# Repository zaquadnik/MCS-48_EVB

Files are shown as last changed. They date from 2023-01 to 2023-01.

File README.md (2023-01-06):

# MCS-48_EVB

Simple computer system using MCS-48 family microcontroller. System contains external program memory & external data memory. The external data memory uses the 62256 (32k x 8b) SRAM memory. The microcontroller directly addresses the 256 bytes of the memory, but the system adds the possibility of bank switching using the 8243 GPIO expander. The bank switching is done in software. It can be leveraged to implement multi-tasking environment with hard task memory separation. The external data memory contains 128 banks, 256 bytes each.
The external program memory uses 8k x 8b 27C64 EPROM memory. The microcontroller max program memory size is 4kB, thus EPROM contain two 4kB banks, that can be switched using the 8243 expander. This feature is experimental, thus HW jumper is added that enables setting the EPROM's A12 line to logical '0' by connecting it to the ground.

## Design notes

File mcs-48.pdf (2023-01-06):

# Grokking the MCS-48 System

## Version 3.5.2, September 2021

# Preface

This document came into existence as the effort to collect and maintain the information about the MCS-48 microcontroller family I have access to.
The collected paperwork consists of several copied sheets from Intel databooks that age over time, slowly fading away. In addition, the resources in electronic form for this microcontroller

## family were never complete nor exhaustive. As nowadays, not everyone is lucky enough to have access to these old, big databooks, this document intends to transport all the

knowledge necessary to work with these grandfathers.
Please note that this document does not claim correctness of the contained information. Nor should you ever use it as the only reference for building critical applications.

## Five separate sources contributed to this document: - Two different versions of the "MCS-48TM Microcomputer User's Manual" The chapter "The Expanded MCS-48TM System" was found in a 1978's copy of the User's Manual while the chapter "The Single Component MCS® -48 System" was probably part of a

later revision of the User's Manual.

## - Das 8039, 8048, 8748 Brevier H. Weidner, Braunschweig The first part of this booklet is a translation of "The Single Component MCS ® -48 System" into the German language while the second part gives a very detailed description of the

family's instruction set.

## - HMOS Single-Component 8-Bit Microcomputer Intel Corporation, August 1982, Order Number 210677-001

A 9-page datasheet with an excellent instruction set table.

- Some scanned pages with details about the 8243, apparently from an old Intel databook.

## - A set of copied pages containing the 8245 product specification. The second page of the

character set is missing.

## October 2006

## Arnim Läuger

mailto: arnim.laeuger <at> gmx.net

The following are trademarks of Intel Corporation and its affiliates and may be used only to identify Intel products: BXP, CREDIT, i, ICE, ICS, im, insite, Intel, INTEL, Intelevision, Intellec, iSBC, iSBX, Library Manager, MCS, MAIN MULTIMODULE, Megachassis, Micromap, MULTIBUS, Plug-A-Bubble, PROMPT, Promware, RMX, UPI, µScope, System 2000, Micromainframe, and the combination of MCS, ICE, iSBC, iRMX or iCS and a numerical suffix.

# HMOS Single-Component 8-Bit Microcomputer

- High Performance HMOS | • Reduced Power Consumption
- Interval Timer/Event Counter | • Compatible with 8080/8085 Peripherals
- Two Single Level Interrupts | • Easily Expandable Memory and I/O
- Single 5-Volt Supply | • Up to 1.36 μs Instruction Cycle
- Over 96 Instructions; 90% Single Byte | All Instructions 1 or 2 Cycles

The Intel MCS®

-48 family are totally self-sufficient, 8-bit parallel computers fabricated on single silicon chips using Intel's advanced N-channel silicon gate HMOS process.
The family contains 27 I/O lines, an 8-bit timer/counter and on-board oscillator/clock circuits. For systems that require extra capability, the family can be expanded using MCS®
| -80/MCS® -85 peripherals.
To minimize development problems and provide maximum flexibility, a logically and functionally pin-compatible version of the ROM devices with UV-erasable user-programmable EPROM program memory is available with minor differences.
These microcomputers are designed to be efficient controllers as well as arithmetic processors. They have extensive bit handling capability as well as facilities for both binary and BCD arithmetic. Efficient use of program memory results from an instruction set consisting mostly of single byte instructions and no instructions over 2 bytes in length.
Device | Internal Memory | RAM Standby
8050AH | 4K x 8 ROM | 256 x 8 RAM | yes
8049H | 2K x 8 ROM | 128 x 8 RAM | yes
8048H | 1K x 8 ROM | 64 x 8 RAM | yes
8040AHL | none | 256 x 8 RAM | yes
8039HL | none | 128 x 8 RAM | yes
8035HL | none | 64 x 8 RAM | yes
8749H | 2K x 8 EPROM | 128 x 8 RAM | yes
8748H | 1K x 8 EPROM | 64 x 8 RAM | yes

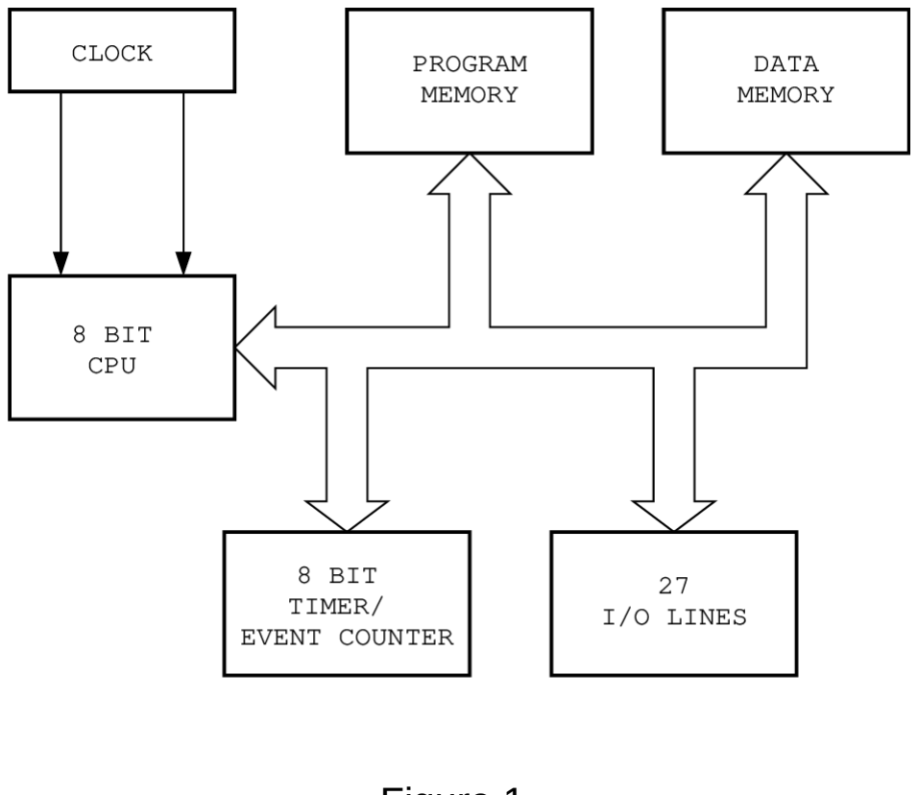
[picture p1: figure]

Figure 1.
Block Diagram

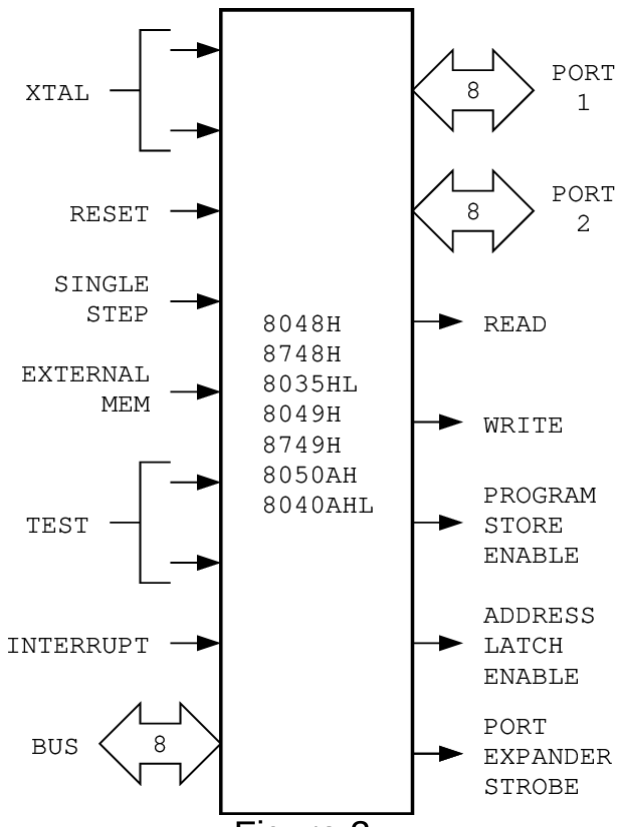
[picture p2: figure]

Figure 2.
Logic Symbol

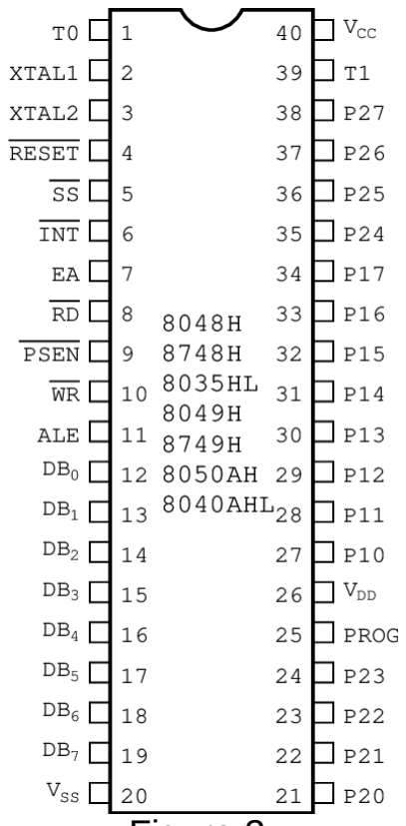
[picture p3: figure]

Figure 3.
Pin Configuration

# THE SINGLE COMPONENT MCS® -48 SYSTEM

## 1.0 INTRODUCTION

Sections 2 through 5 describe in detail the functional characteristics of the 8748H and 8749H EPROM,
8048AH/8049AH/8050AH | ROM | and | 8035AHL/
8039AHL/8040AHL CPU single component microcomputers. Unless otherwise noted, details within these sections apply to all versions. This chapter is limited to those functions useful in single-chip implementations of the MCS®

-48. The Chapter on the Expanded MCS®

| | | -48
System discusses functions which allow expansion of program memory, data memory, and input output capability.

## 2.0 ARCHITECTURE

The following sections break the MCS-48 Family into functional blocks and describe each in detail. The following description will use the 8048AH as the representative product for the family. See 4.

## 2.1 Arithmetic Section

The arithmetic section of the processor contains the basic data manipulation functions of the 8048AH and can be divided into the following blocks:
- Arithmetic Logic Unit (ALU)
- Accumulator
- Carry Flag
- Instruction Decoder

In a typical operation data stored in the accumulator is combined in the ALU with data from another source on the internal bus (such as a register or I/O port) and the result is stored in the accumulator or another register.

The following is more detailed description of the function of each block.

## INSTRUCTION DECODER

The operation code (op code) portion of each program instruction is stored in the Instruction Decoder and is converted to outputs which control the function of each of the blocks of the Arithmetic Section. These lines control the source of data and the destination register as well as the function performed in the ALU.

## ARITHMETIC LOGIC UNIT

The ALU accepts 8-bit data words from one or two sources and generates an 8-bit result under control of the Instruction Decoder. The ALU can perform the following functions:

- Add With or Without Carry
- AND, OR, Exclusive OR
- Increment/Decrement
- Bit Complement
- Rotate Left, Right
- Swap Nibbles
- BCD Decimal Adjust

If the operation performed by the ALU results in a value represented by more than 8 bits (overflow of most significant bit), the Carry Flag is set in the Program Status Word.

## ACCUMULATOR

The accumulator is the single most important data register in the processor, being one of the sources of input to the ALU and often the destination of the result of operations performed by the ALU. Data to and from I/O ports and memory also normally passes through the accumulator.

## 2.2 Program Memory

Resident program memory consists of 1024, 2048 or 4096 words eight bit wide which are addressed by the program counter. In the 8748H and the 8749H this memory is user programmable and erasable EPROM; in the 8048AH/ 8049AH/8050AH the memory is ROM which is mask programmable at the factory. The 8035AHL/8039AHL/ 8040AHL has no internal program memory and is used with external memory devices. Program code is completely interchangeable among the various versions. To access the upper 2K of program memory in the 8050AH and other MCS-48 devices, a select memory bank and a JUMP or CALL instruction must be executed to cross the 2K boundary.

There are three locations in Program Memory of special importance as shown in 5.

LOCATION 0
Activating the Reset line of the processor causes the first instruction to be fetched from location 0.

LOCATION 3
Activating the Interrupt input line of the processor (if interrupt is enabled) causes a jump to subroutine at location 3.

LOCATION 7
A timer/counter interrupt resulting from timer counter overflow (if enabled) causes a jump to subroutine at location 7.

Therefore, the first instruction to be executed after initialization is stored in location 0, the first word of an external interrupt service subroutine is stored in location 3 and the first word of a timer/counter service routines is stored in location 7. Program memory can be used to

4

## SINGLE COMPONENT MCS® -48 SYSTEM

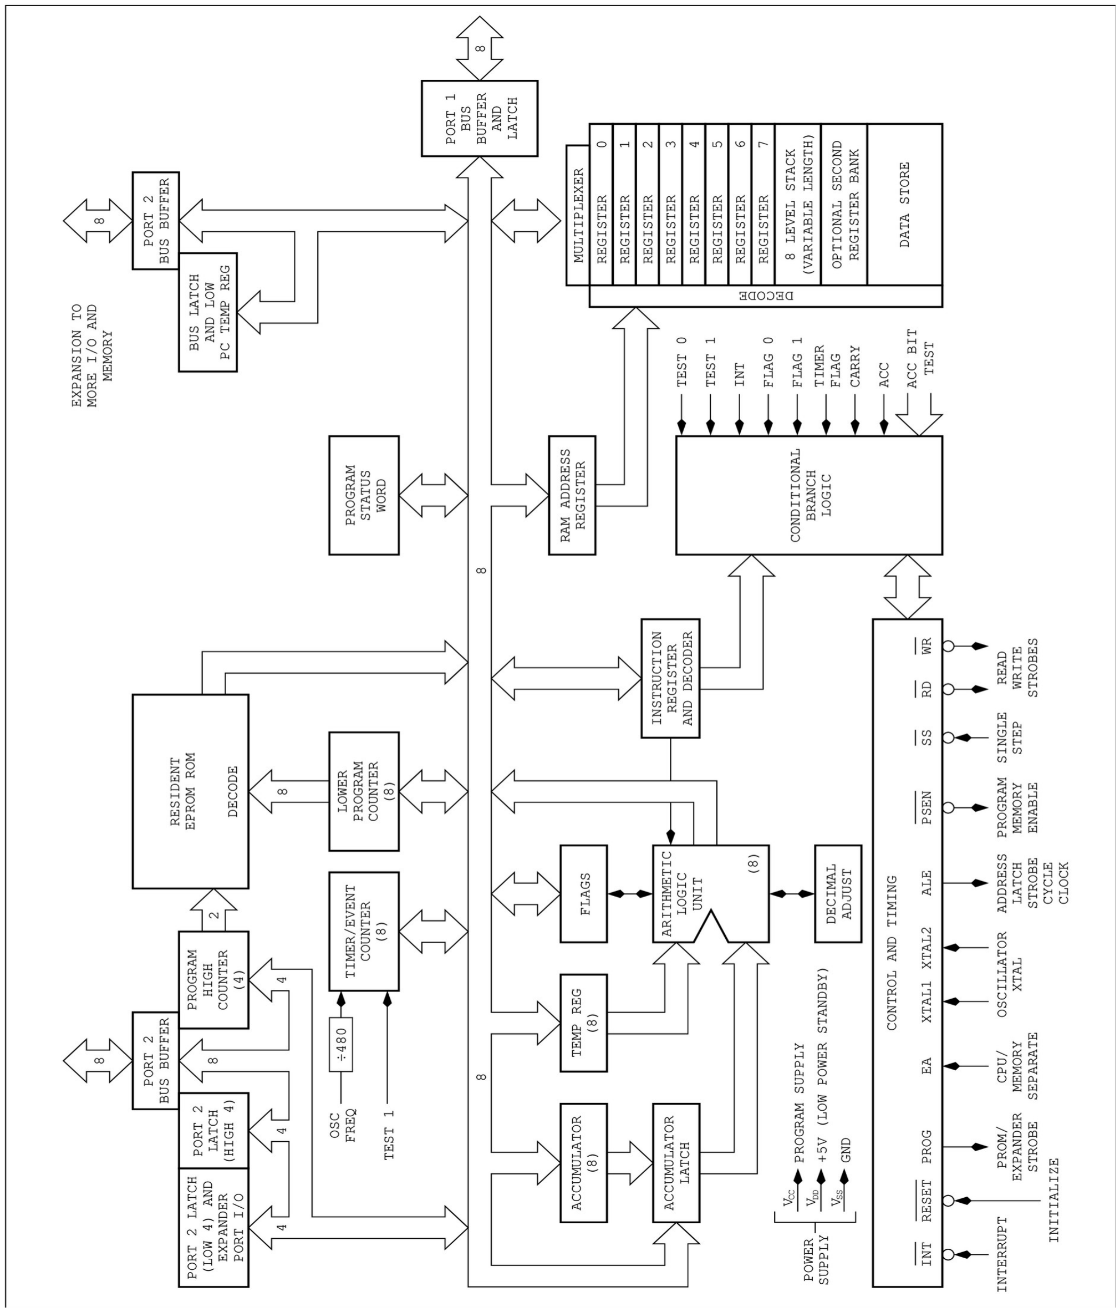
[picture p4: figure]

5

Figure 4: 8748H/8048H/8749AH/8050AH Block Diagram store constants as well as program instructions. Instructions such as MOVP and MOVP3 allow easy access to data "lookup" tables.

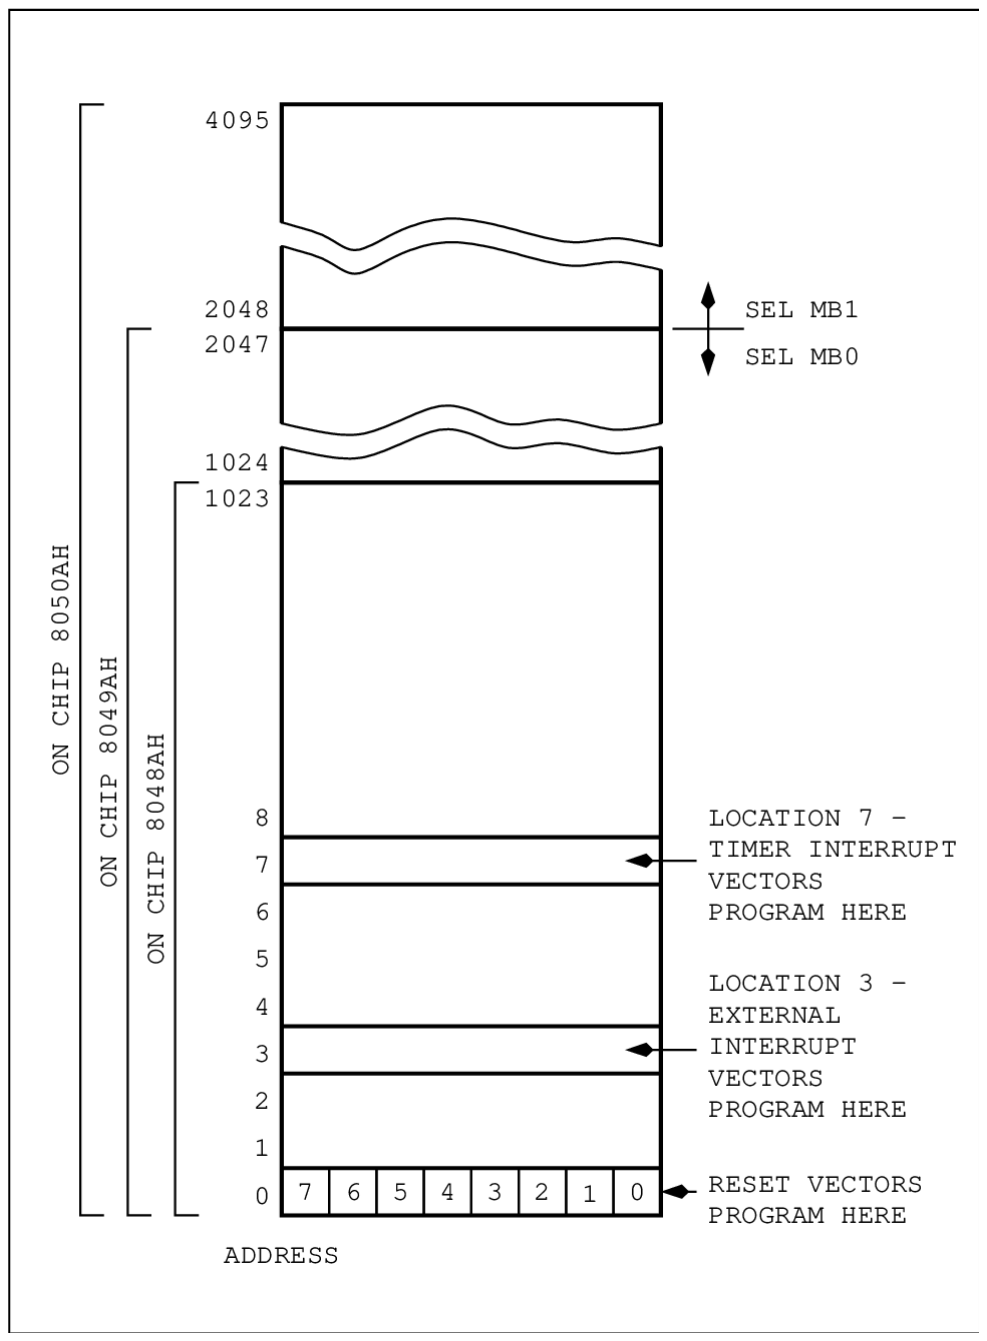
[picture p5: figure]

## 2.3 Data Memory

Resident data memory is organized as 64, 128 or 256 by 8-bits wide in the 8048AH, 8049AH and 8058AH. All locations are indirectly addressable through either of two RAM Pointer Registers which reside at address 0 and 1 of the register array. In addition, as shown in 6, the first 8 locations (0-7) of th array are designated as working registers and are directly addressable by several instructions. Since these registers are more easily addressed, they are usually used to store frequently accessed intermediate results. The DJNZ instruction makes very efficient use of the working registers as program loop counters by allowing the programmer to decrement and test the register in a single instruction.

By executing a Register Bank Switch instruction (SEL RB), RAM locations 24-31 are designated as the working registers in place of locations 0-7 and are then directly addressable. This second bank of working registers may be used as an extension of the first bank or reserved for use during interrupt service subroutines allowing the registers of Bank 0 used in the main program to be instantly "saved" by a Bank Switch. Note that if this second bank is not used, locations 24-31 are still addressable as general purpose RAM. Since the two RAM pointer Registers R0 and R1 are a part of the working register array, bank switch effectively creates two more pointer registers (R0/ and R1/) which can be used with R0 and R1 to easily access up to four separate working areas in RAM at one time. RAM locations 8-23 also serve a dual role in that they contain the program counter stack as explained in Section 2.6. These locations are addressed by the Stack Pointer during subroutine calls as well as by RAM Pointer Registers R0 and R1. If the level of subroutine nesting is less than 8, all stack registers are not required and can be used as general purpose RAM locations. Each level of subroutine nesting not used provides the user with two additional RAM locations.

6

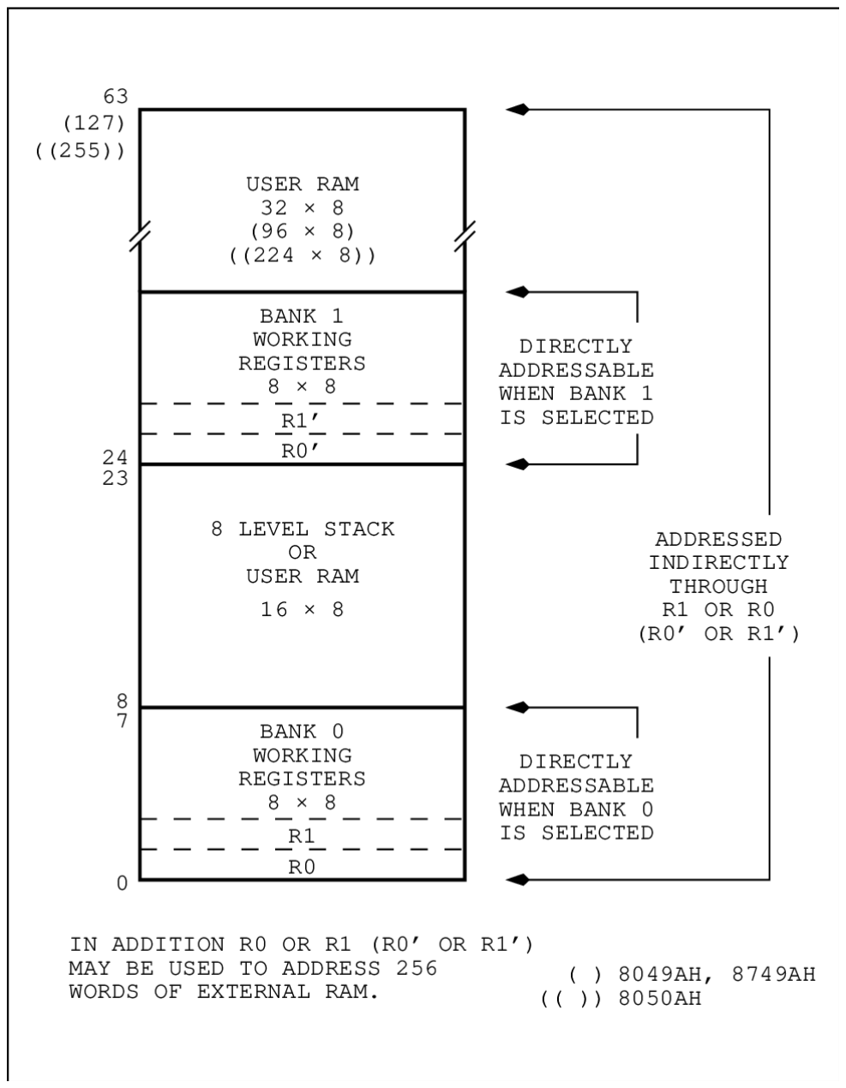
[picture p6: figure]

Figure 6. Data Memory Map

Figure 5. Program Memory Map

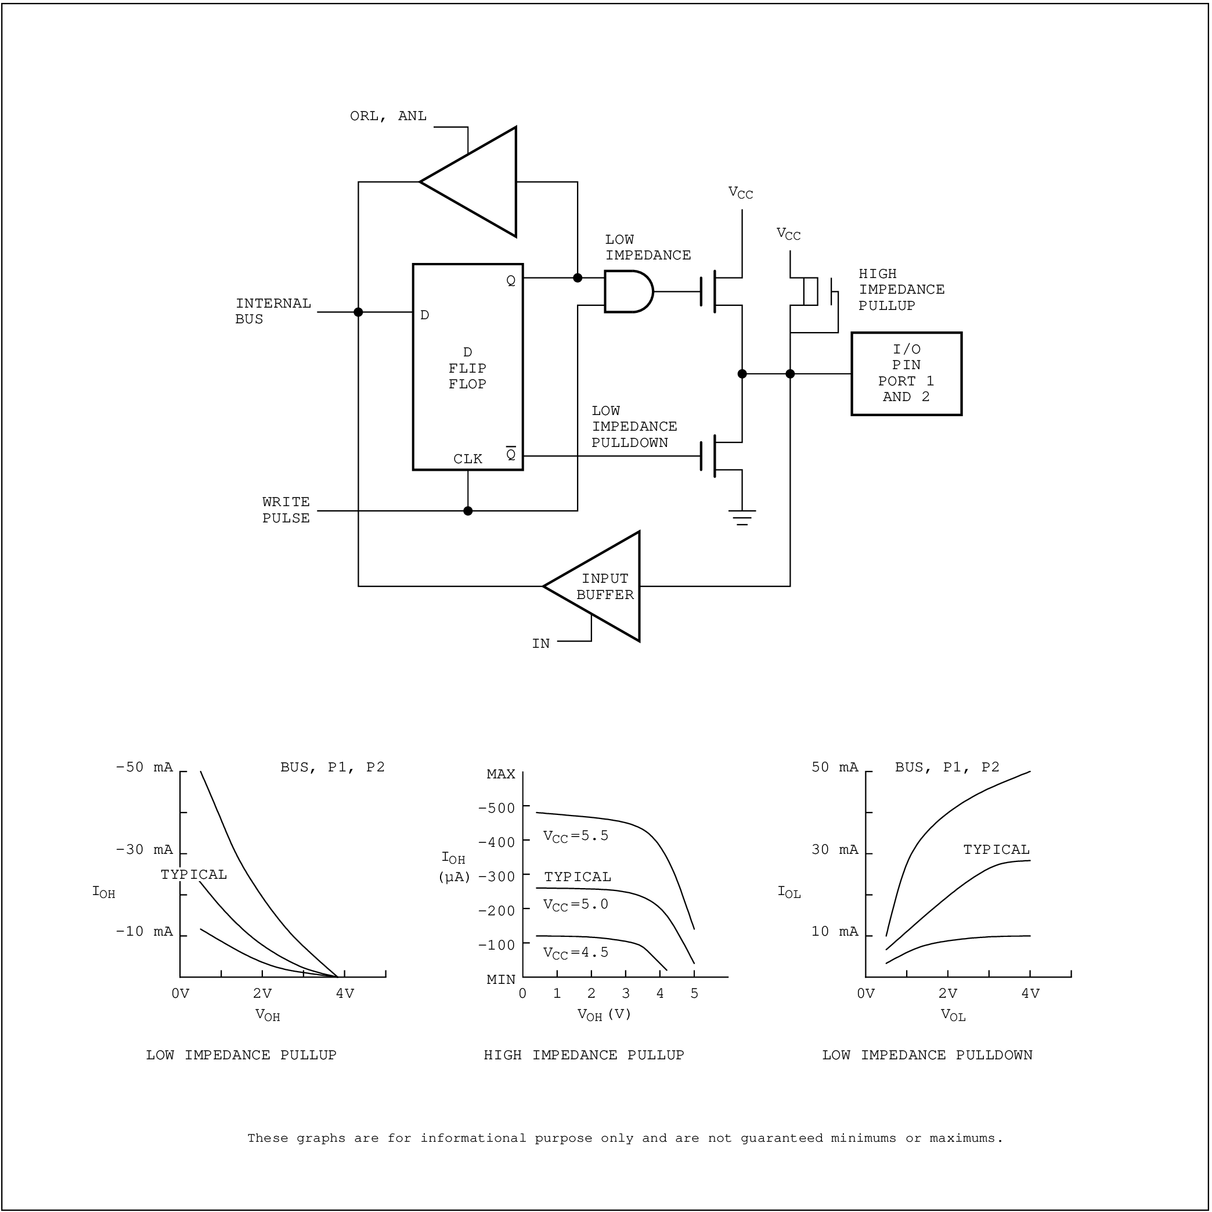
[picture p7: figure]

7

Figure 7. "Quasi-bidirectional" Port Structure

## 2.4 Input/Output

The 8048AH has 27 lines which can be used for input or output functions. These lines are grouped as 3 ports of 8 lines each which serve as either inputs, outputs or bidirectional ports and 3 "test" inputs which can alter program sequences when tested by conditional jump instructions.

## PORTS 1 AND 2

Ports 1 and 2 are each 8 bits wide and have identical characteristics. Data written to these ports is statically latched and remains unchanged until rewritten. As input ports these lines are non-latching, i. e., inputs must be present until read by an input instruction. Inputs are fully TTL compatible and outputs will drive one standard TTL load.

The lines of ports 1 and 2 are called quasi-bidirectional because of a special output circuit structure which allows each line to serve as an input and output or both even though outputs are statically latched. 7 shows the circuit configuration in detail. Each line is continuously pulled to VCC through a resistive device of relatively high impedance.

This pullup is sufficient to provide the source current for a TTL high level yet can be pulled low by a standard TTL gate thus allowing the same pin to be used for both input and output. To provide fast switching times in a "0" to "1" transition a relatively low impedance device is switched in momentarily (≈ 1/5 of a machine cycle) whenever a "1" is written to the line. When a "0" is written to the line, a low impedance device overcomes the light pullup and provides TTL current sinking capability. Since the pulldown transistor is a low impedance device a "1" must first be written to any line which is to be used as an input. Reset initializes all lines to the high impedance "1" state.

It is important to note that the ORL and the ANL are read/ write operations. When executed, the μC "reads" the port, modifies the data according to the instruction, then "writes" the data back to the port. The "writing" (essentially an OUTL instruction) enables the low impedance pull-up momentarily again even if the data was unchanged from a "1". This specifically applies to configurations that have inputs and outputs mixed together on the same port. See also section 8 in the Expanded MCS-48 System chapter.

## BUS

Bus is also an 8-bit port which is a true bidirectional port with associated input and output strobes. If the bidirectional feature is not needed, Bus can serve as either a statically latched output port or non-latching input port. Input and output lines on this port cannot be mixed however.

As a static port, data is written and latched using the OUTL instruction and inputted using the INS instruction. The INS and OUTL instructions generate pulses on the corresponding RD' and WR' output strobe lines; however, in the static port mode they are generally not used. As a bidirectional port the MOVX instructions are used to read and write the port. A write to the port generates a pulse on the WR' output line and output data is valid at the trailing edge of WR'. A read of the port generates a pulse on the RD' output line and input data must be valid at the trailing edge of RD'. When not being written or read, the BUS lines are in a high impedance state. See also sections 7 and 8 in the Expanded MCS-48 System chapter.

## 2.5 Test and INT Inputs

Three pins serve as inputs and are testable with the conditional jump instructions. These are T0, T1, and INT'. These pins allow inputs to cause program branches without the necessity to load an input port into the accumulator. The T0, T1, and INT' pins have other possible functions as well. See the pin description in Section 3.

## 2.6 Program Counter and Stack

The Program Counter is an independent counter while the Program Counter Stack is implemented using pairs of registers in the Data Memory Area. Only 10, 11 or 12 bits of the Program Counter are used to address the 1024, 2048 or 4096 words of on-board program memory of the 8048AH, 8049AH or 8050AH, while the most significant bits can be used for external Program Memory fetches. See 8. The Program Counter is initialized to zero by activating the Reset line.

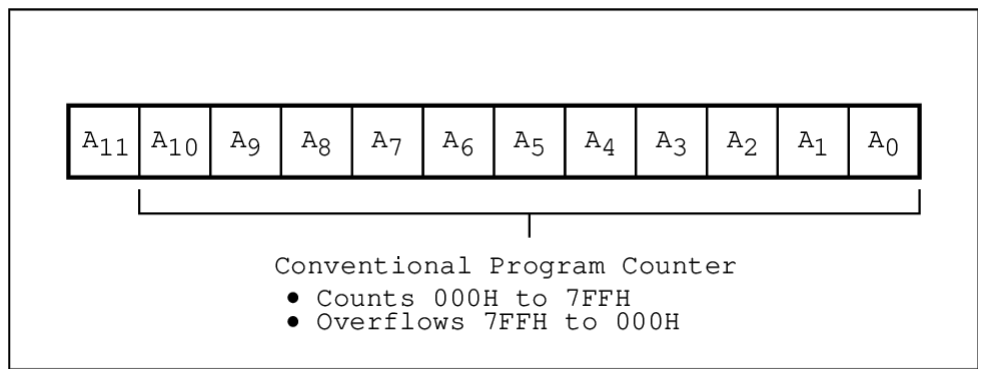
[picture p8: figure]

An interrupt or CALL to a subroutine causes the contents of the program counter to be stored in one of the 8 register pairs of the Program Counter Stack as shown in 9. The pair to be used is determined by a 3-bit Stack Pointer which is part of the Program Status Word (PSW).

8

Figure 8. Program Counter

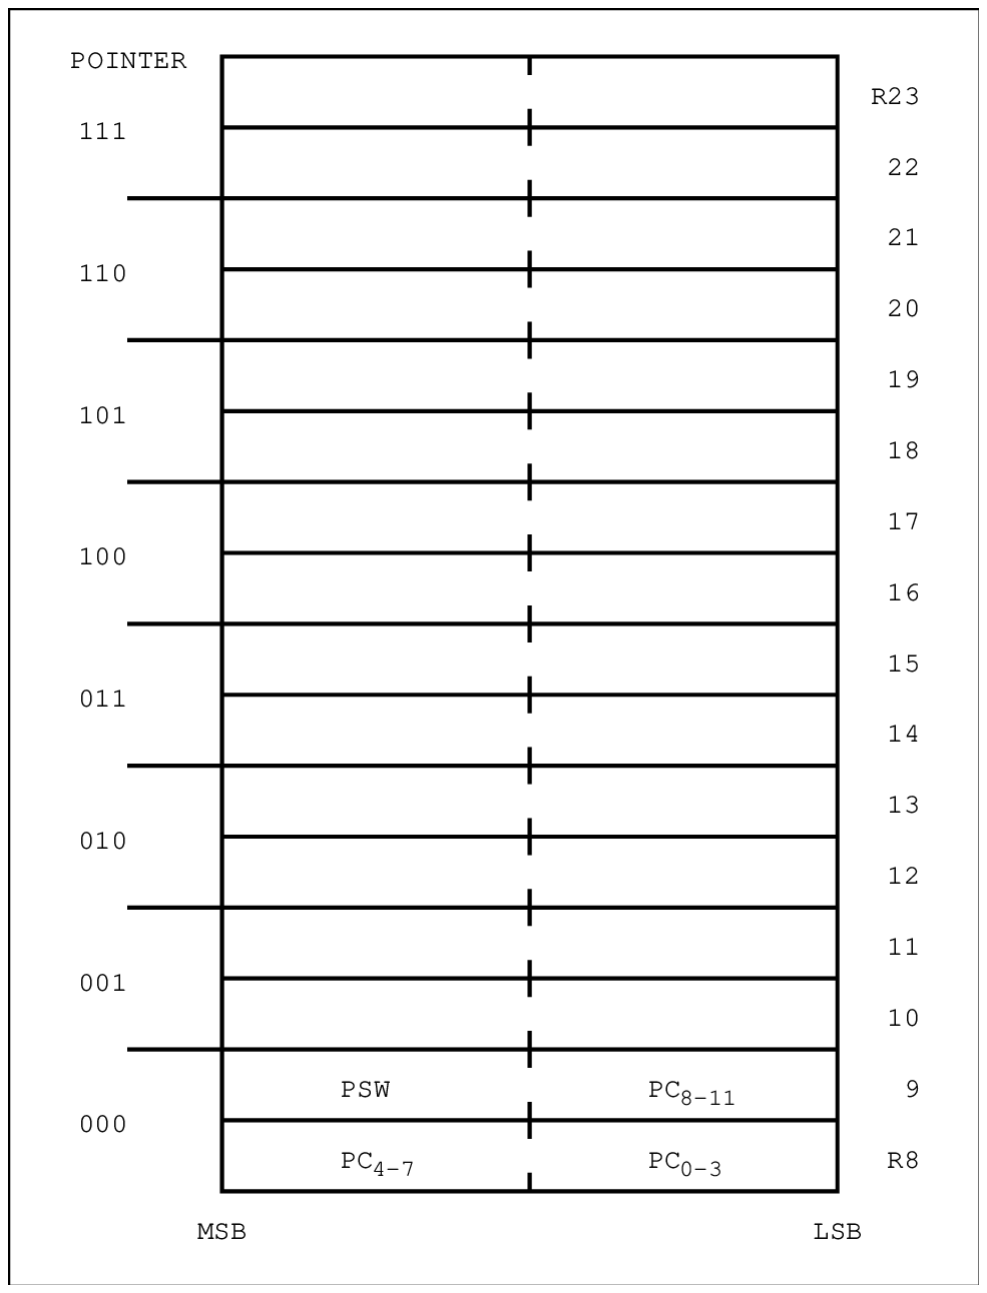
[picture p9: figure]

Data RAM locations 8-23 are available as stack registers and are used to store the Program Counter and 4 bits of PSW as shown in 9. The Stack Pointer when initialized to 000 points to RAM location 8 and 9. The first subroutine jump or interrupt results in the program counter contents being transferred to locations 8 and 9 of the RAM array. The stack pointer is then incremented by one to point to locations 10 and 11 in anticipation of another CALL. Nesting of subroutines within subroutines can continue up to 8 times without overflowing the stack. If overflow does occur, the deepest address stored (locations 8 and 9) will be overwritten and lost since the stack pointer overflows from 111 to 000. It also underflows from 000 to 111.

The end of a subroutine, which is signaled by a return instruction (RET or RETR), causes the Stack Pointer to be decremented and the contents of the resulting register pair to be transferred to the Program Counter.

## 2.7 Program Status Word

An 8-bit status word which can be loaded to and from the accumulator exists called the Program Status Word (PSW). 10 shows the information available in the word. The Program Status Word is actually a collection of flipflops throughout the machine which can be read or written as a whole. The ability to write the PSW allows for easy restoration of machine status after a power down sequence.

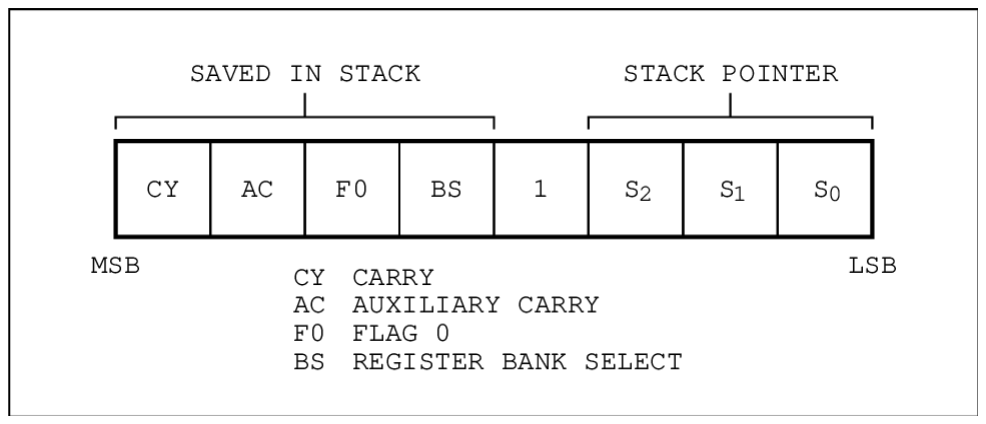
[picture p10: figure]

The upper four bits of PSW are stored in the Program Counter Stack with every call to subroutine or interrupt vector and are optionally restored upon return with the RETR instruction. The RET return instruction does not update PSW.

The PSW bit definitions are as follows:

Bits 0-2: | Stack Pointer bits (S0, S1, S2)
Bit 3: | Not used ("1" level when read)
Bit 4: | Working Register Bank Switch Bit (BS) 0 = Bank 0 1 = Bank 1
Bit 5: | Flag 0 bit (F0) user controlled flag which can be complemented or cleared and tested with the conditional jump instruction JF0.
Bit 6: | Auxiliary Carry (AC) carry bit generated by an ADD instruction and used by the decimal adjust instruction DA A.
Bit 7: | Carry (CY) carry flag which indicates that the previous operation has resulted in overflow of the accumulator.

## 2.8 Conditional Branch Logic

The conditional branch logic within the processor enables several conditions internal and external to the processor to be tested by the user program. By using the conditional jump instruction the conditions that are listed in 1 can affect a change in the sequence of the program execution.

9

Figure 10. Program Status Word (PSW)

Figure 9. Program Counter Stack

Table 1

Device Testable | Jump Condition (Jump On)
Accumulator Accumulator Bit Carry Flag User Flags (F0, F1) Timer Overflow Flag Test Inputs (T0, T1) Interrupt Input (INT) | All zeros ---0 ------0 0 | not all zeros 1 1 1 1 1 ---

## 2.9 Interrupt

An interrupt sequence is initiated by applying a low "0" level input to the INT' pin. Interrupt is level triggered and active low to allow "WIRE ORing" of several interrupt sources at the input pin. 11 shows the interrupt logic of the 8048AH. The interrupt line is sampled every instruction cycle and when detected causes a "call to subroutine" at location 3 in program memory as soon as all cycles of the current instruction are complete. On 2-cycle instructions the interrupt line is sampled on the 2nd cycle only. INT' must be held low for at least 3 machine cycles to ensure proper interrupt operations. As in any CALL to subroutine, the Program Counter and Program Status word is saved in the stack. For a description of this operation see the previous section, Program Counter and Stack. Program Memory location 3 usually contains an unconditional jump to an interrupt service subroutine elsewhere in program memory. The end of an interrupt service subroutine is signaled by the execution of a Return and Restore Status instruction RETR. The interrupt system is single level in that once an interrupt is detected all further interrupt requests are ignored until execution of an RETR reenables the interrupt input logic. This occurs at the beginning of the second cycle of the RETR instruction. This sequence holds true also for an internal interrupt generated by timer overflow. If an internal timer/counter generated interrupt and an external source will be recognized at the same time, the external source will be recognized. See the following Timer/Counter section for a description of timer interrupt. If needed, a second external interrupt can be created by enabling the timer/counter interrupt, loading FFH in the Counter (one less than terminal count) and enabling the event counter mode. A "1" to "0" transition on the T1 input will then cause an interrupt vector to location 7.

## INTERRUPT TIMING

The interrupt input may be enabled or disabled under Program Control using the EN I and DIS I instructions. Interrupts are disabled by Reset and remain so until enabled by the user's program. An interrupt request must be removed before the RETR instruction is executed upon return from the service subroutine otherwise the processor will re-enter the service routine immediately. Many peripheral devices prevent this situation by resetting their interrupt request line whenever the processor accesses (Reads or Writes) the peripheral's data buffer register. If the interrupt device does not require access by the processor, one output line of the 8048AH may be designated as an "interrupt acknowledge" which is activated by the service subroutine to reset the interrupt request. The INT' pin may also be tested using the conditional jump instruction JNI. This instruction may be used to detect the presence of a pending interrupt before interrupts are enabled. If interrupt is left disabled, INT' may be used as another test input like T0 and T1.

## 2.10 Timer/Counter

The 8048AH contains a counter to aid the user in counting external events and generating accurate time delays without placing a burden on the processor for these functions. In both modes the counter operation is the same, the only difference being the source of the input to the counter. The timer/event counter is show in 12.

## COUNTER

The 8-bit binary counter is presettable and readable with the MOV instructions which transfer the contents of the accumulator to the counter and vice versa. The counter content may be affected by Reset and should be initialized by software. The counter is stopped by a Reset or STOP TCNT instruction and remains stopped until started as a timer by a STRT T instruction or as an event counter by a STRT CNT instruction. Once started, the counter will increment to this maximum count (FF) and overflow to zero continuing its count until stopped by a STOP TCNT instruction or Reset.

The increment from maximum count to zero (overflow) results in the setting of an overflow flag flip-flop and in the generation of an interrupt request. The state of the overflow flag is testable with the conditional jump instruction JTF. The flag is reset by executing a JTF or by Reset. The interrupt request is stored in a latch and then ORed with the external interrupt input INT. The timer interrupt may be enabled or disabled independently of external interrupt by the EN TCNTI and DIS TCNTI instructions. If enabled, the counter overflow will cause a subroutine call to location 7 where the timer or counter service routine may be stored.

10

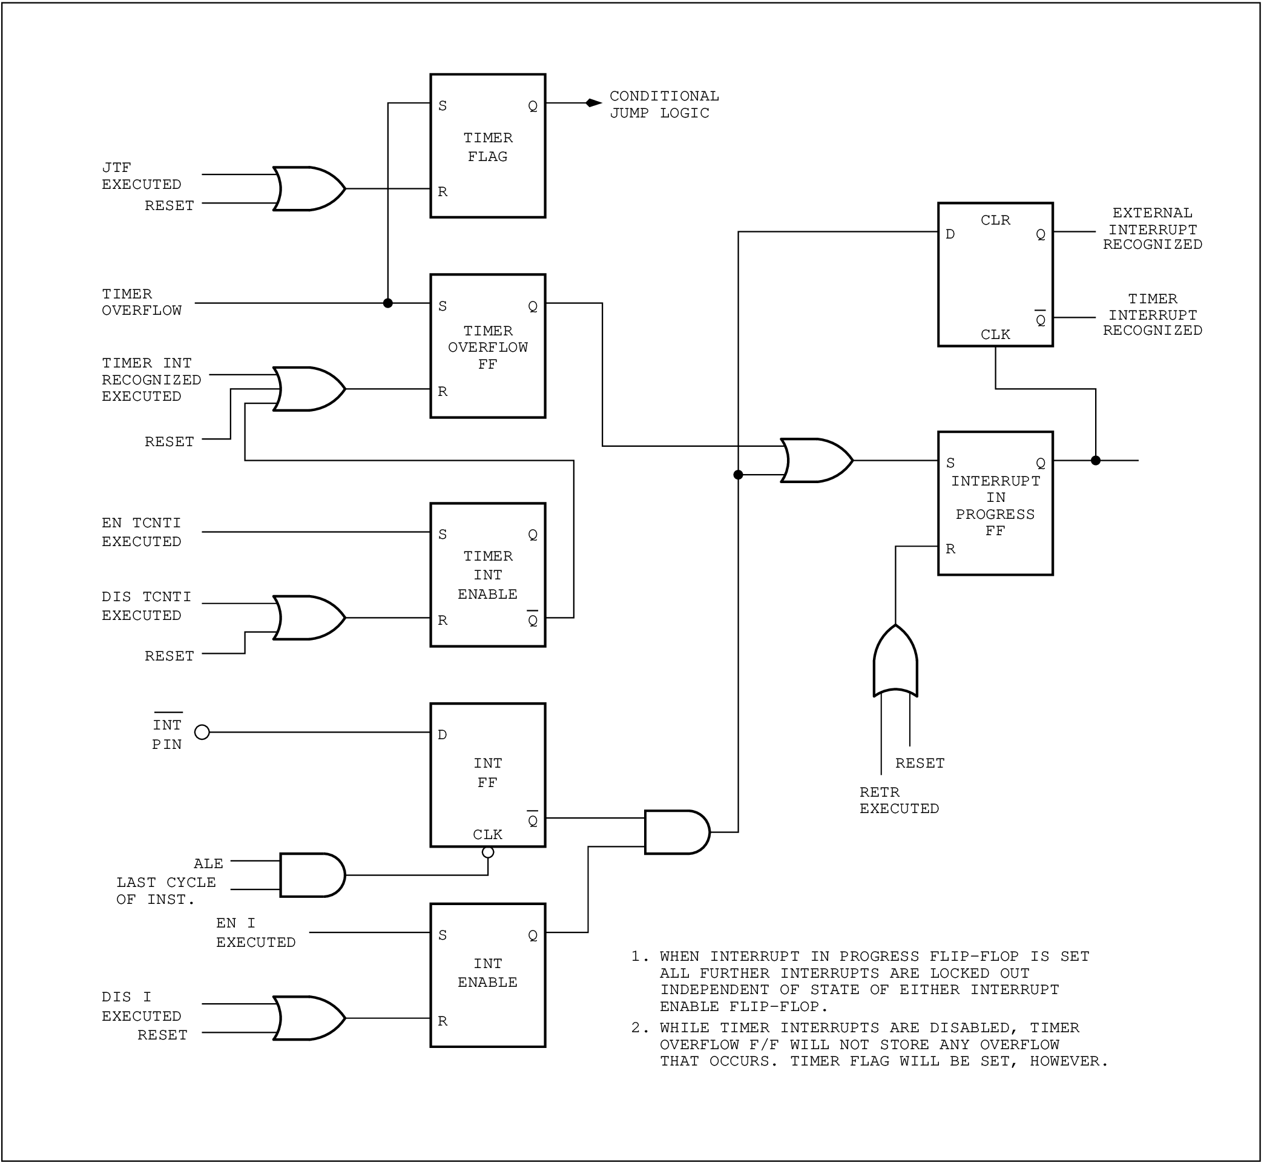
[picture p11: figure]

11

Figure 11. Interrupt Logic

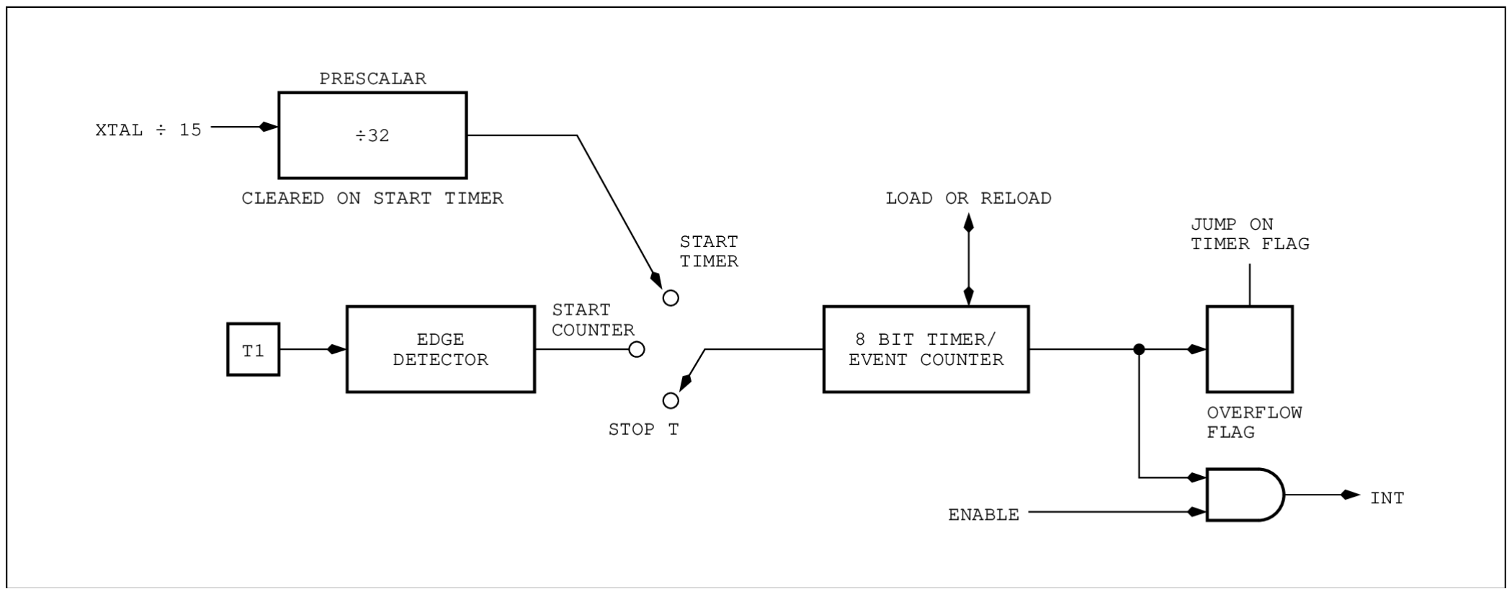
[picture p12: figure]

If timer and external interrupts occur simultaneously, the external interrupt will be recognized and the Call will be to location 3. Since the timer interrupt is latched it will remain pending until the external device is serviced and immediately be recognized upon return from the service routine. The pending timer interrupt is reset by the Call to location 7 or may be removed by executing a DIS TCNTI instruction.

## AS AN EVENT COUNTER

Execution of a START CNT instruction connects the T1 input pin to the counter input and enables the counter. The T1 input is sampled at the beginning of state 3 or in later MCS-48 devices in state time 4. Subsequent high to low transitions on T1 will cause the counter to increment. T1 must be held low for at least 1 machine cycle to ensure it won't be missed. The maximum rate at which the counter may be incremented is once per three instruction cycles (every 5.7 µsec when using an 8 MHz crystal) --- there is no minimum frequency. T1 input must remain high for at least 1/5 machine cycle after each transition.

## AS A TIMER

Execution of a START T instruction connects an internal clock to the counter input and enables the counter. The internal clock is derived by passing the basic machine cycle clock through a ÷ 32 prescaler. The prescaler is reset during the START T instruction. The resulting clock increments the counter every 32 machine cycles. Various delays from 1 to 256 counts can be obtained by presetting the counter and detecting overflow. Times longer than 256 counts may be achieved by accumulating multiple overflows in a register under software control. For time resolution less than 1 count an external clock can be applied to the T1 input and the counter operated in the event counter mode. ALE divided by 3 or more can serve as this external clock. Very small delays or "fine tuning" of larger delays can be easily accomplished by software delay loops.

Often a serial link is desirable in an MCS-48 family member. 2 lists the timer counts and cycles needed for a specific baud rate given a crystal frequency.

## 2.11 Clock and Timing Circuits

Timing generation for the 8048AH is completely self contained with the exception of a frequency reference which can be XTAL, ceramic resonator or external clock source. The Clock and Timing circuitry can be divided into the following functional blocks.

## OSCILLATOR

The on-board oscillator is a high gain parallel resonant circuit with a frequency range of 1 to 11 MHz. The X1 external pin is the input to the amplifier stage while X2 is the output. A crystal or ceramic resonator connected between X1 and X2 provides the feedback and phase shift required for oscillation. If an accurate frequency reference is not required, ceramic resonator may be used in place of the crystal.

For accurate clocking, a crystal should be used. An externally generated clock may also be applied to X1—X2 as the frequency source. See the data sheet for more information.

12

Figure 12. Timer/Event Counter

## STATE COUNTER

The output of the oscillator is divided by 3 in the State Counter to create a clock which defines the state times of the machine (CLK). CLK can be made available on the external pin T0 by executing an ENT0 CLK instruction. The output of CLK on T0 is disabled by Reset of the processor.

## CYCLE COUNTER

CLK is then divided by 5 in the Cycle Counter to provide a clock which defines a machine cycle consisting of 5 machine states as shown in 13. 14 shows the different internal operations as divided into the machine states. This clock is called Address Latch Enable (ALE) because of its function in MCS-48 systems with external memory. It is provided continuously on the ALE output pin.

## 2.12 Reset

The reset input provides a means for initialization for the processor. This Schmitt-trigger input has an internal pullup device which in combination with an external 1 µF capacitor provides an internal reset pulse of sufficient length to guarantee all circuitry is reset, as shown in 15. If the reset pulse is generated externally, the RESET pin must be held low for at least 10 milliseconds after the power supply is within tolerance. Only 5 machine cycles

(6.8 µs @ 11 MHz) are required if power is already on and the oscillator has stabilized. ALE and PSEN (if EA = 1) are active while in Reset.

Reset performs the following functions:

1) Sets program counter to zero.
2) Sets stack pointer to zero.
3) Selects register bank 0.
4) Selects memory bank 0.
5) Sets BUS to high impedance state (except when EA = 5 V).
6) Sets Ports 1 and 2 to input mode.
7) Disables interrupts (timer and external).
8) Stops timer.
9) Clears timer flag.
10) Clears F0 and F1.
11) Disables clock output from T0.

13

Table 2. Baud Rate Generation

Frequency (MHz) | TCY | T0 Prr(1/5 TCY) | Timer Prescaler (32 TCY)
4 6 8 11 | 3.75 µs 2.50 µs 1.88 µs 1.36 µs | 750 ns 500 ns 375 ns 275 ns | 120 µs 80 µs 60.2 µs 43.5 µs
Baud Rate | 4 MHz Timer Counts + Instr. Cycles | 6 MHz Timer Counts + Instr. Cycles | 8 MHz Timer Counts + Instr. Cycles | 11 MHz Timer Counts + Instr. Cycles
110 | 75 + 24 Cycles .01% Error | 113 + 20 Cycles .01% Error | 151 + 3 Cycles .01% Error | 208 + 28 Cycles .01% Error
300 | 27 + 24 Cycles .1% Error | 41 + 21 Cycles .03% Error | 55 + 13 Cycles .01% Error | 76 + 18 Cycles .04% Error
1200 | 6 + 30 Cycles .1% Error | 10 + 13 Cycles .1% Error | 12 + 27 Cycles .06% Error | 19 + 4 Cycles .12% Error
1800 | 4 + 20 Cycles .1% Error | 6 + 30 Cycles .1% Error | 9 + 7 Cycles .17% Error | 12 + 24 Cycles .12% Error
2400 | 3 + 15 Cycles .1% Error | 5 + 6 Cycles .4% Error | 6 + 24 Cycles .29% Error | 9 + 18 Cycles .12% Error
4800 | 1 + 23 Cycles 1.0% Error | 2 + 19 Cycles .4% Error | 3 + 14 Cycles .74% Error | 4 + 25 Cycles .12% Error

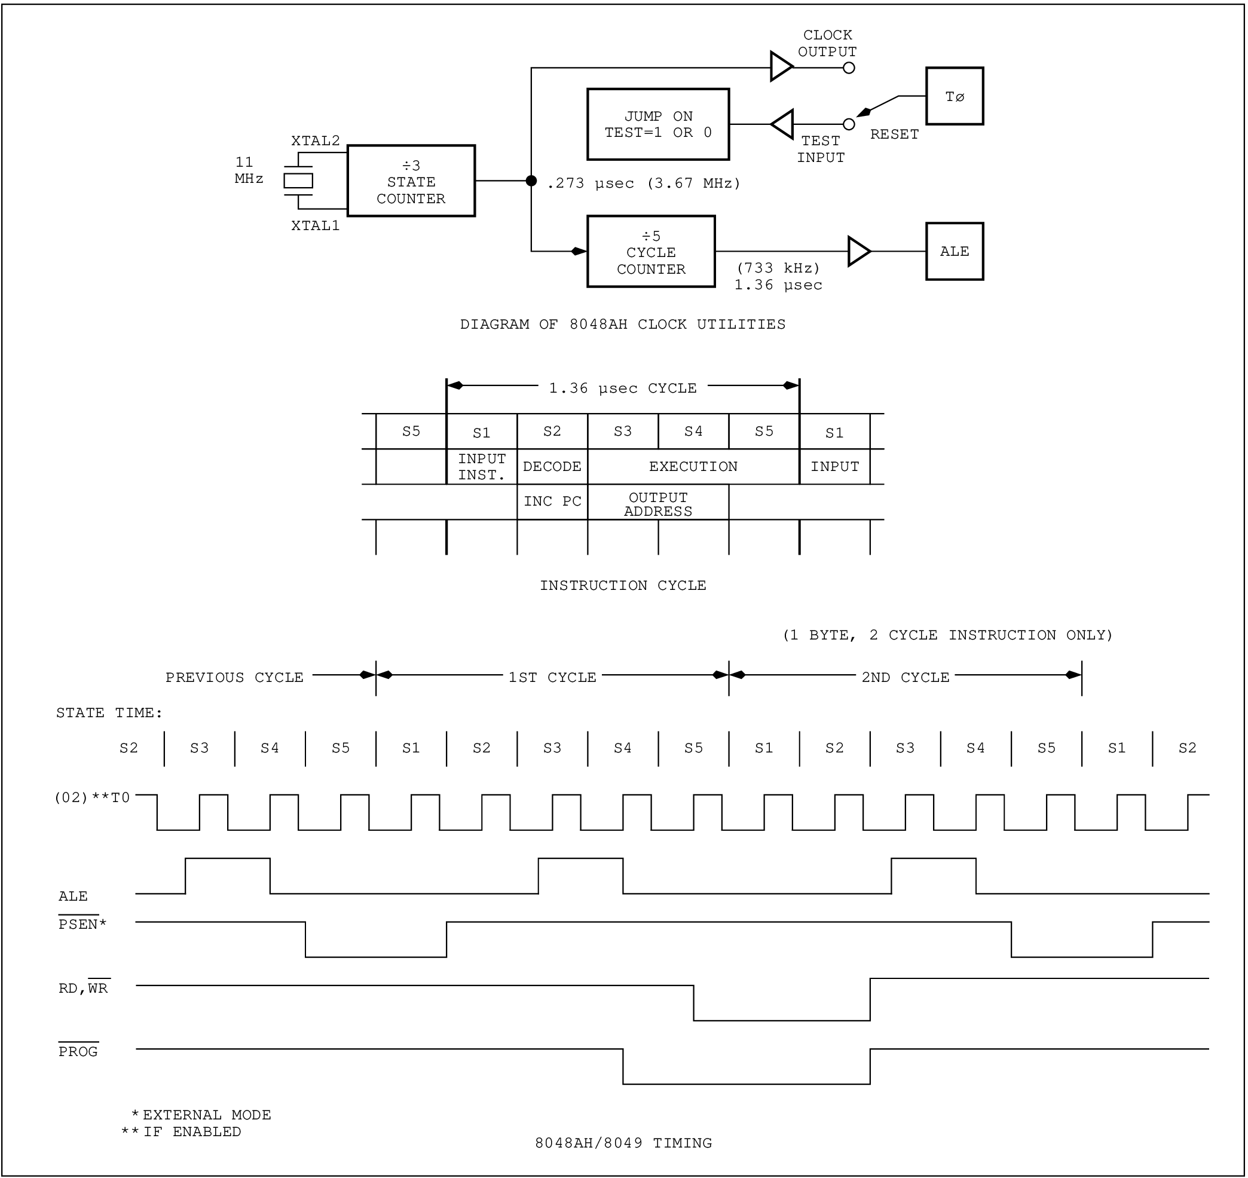
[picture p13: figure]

## 2.13 Single-Step

This feature, as pictured in 16, provides the user with a debug capability in that the processor can be stepped through the program one instruction at a time. While stopped, the address of the next instruction to be fetched is available concurrently on BUS and the lower half of Port
2. The user can therefore follow the program through each of the instruction steps. A timing diagram, showing the interaction between output ALE and input SS', is shown. The BUS buffer contents are lost during single step; however, a latch may be added to reestablish the lost I/O capability if needed. Data is valid at the leading edge of ALE.

14

Figure 13. MCS-48 Timing Generation and Cycle Timing

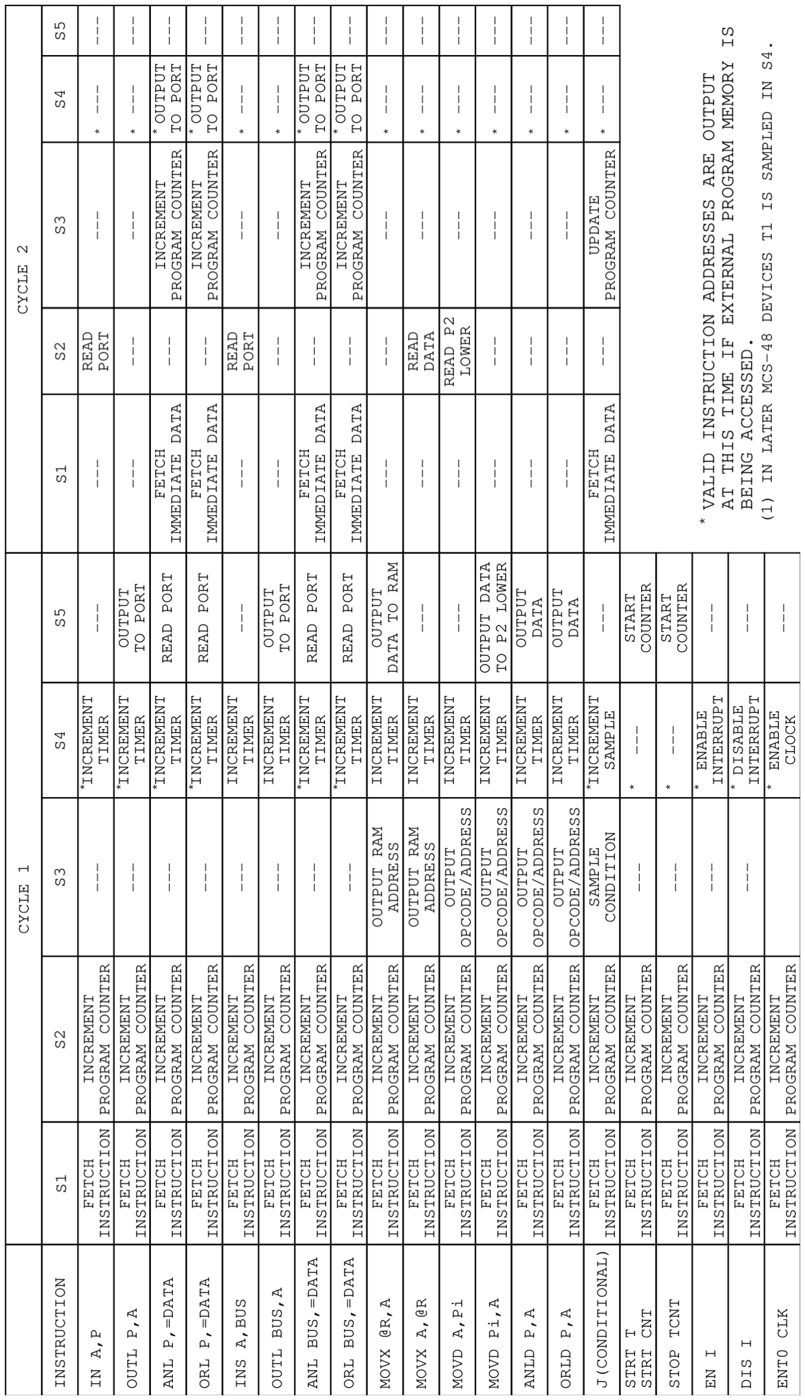
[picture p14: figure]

15

Figure 14. 8048AH/8049AH Instruction Timing Diagram

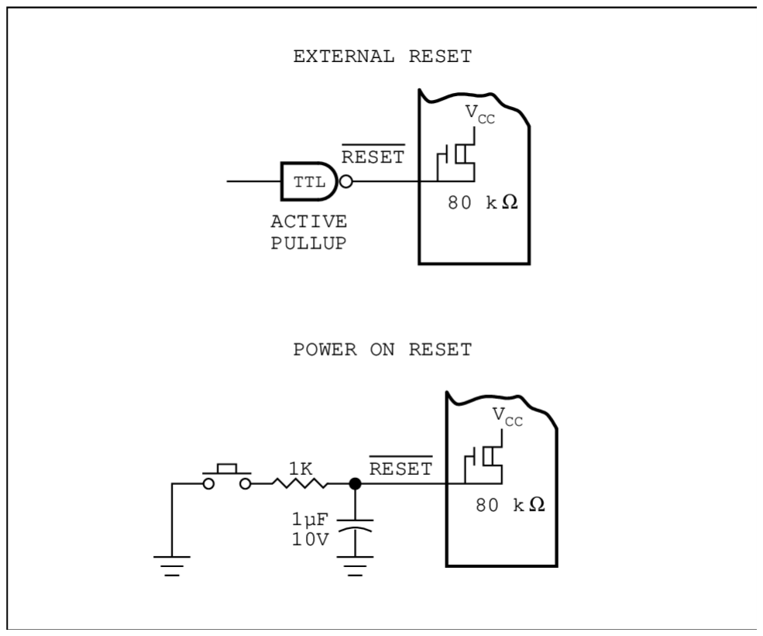
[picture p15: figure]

## TIMING

The 8048AH operates in a single-step mode as follows:

1) The processor is requested to stop by applying a low level on SS'.
2) The processor responds by stopping during the address fetch portion of the next instruction. If a double cycle instruction is in progress when the single step command is received, both cycles will be completed before stopping.
3) The processor acknowledges it has entered the stopped state by raising ALE high. In this state (which can be maintained indefinitely) the address of the next instruction to be fetched is present on BUS and the lower half of port 2.
4) SS' is then raised high to bring the processor out of the stopped mode allowing it to fetch the next instruction. The exit from stop is indicated by the processor brining ALE low.
5) To stop the processor at the next instruction, SS' must be brought low again soon after ALE goes low. If SS' is left high the processor remains in a "Run" mode.

A diagram for implementing the single-step function of the 8748Ah is show in 16. D-type flip-flop with preset and clear is used to generate SS'. In the run mode SS' is held high by keeping the flip-flop preset (preset has precedence over the clear input). To enter single step, preset is removed allowing ALE to bring SS' low via the clear input. ALE should be buffered since the clear input of an SN7474 is the equivalent of 3 TTL loads. The processor is now in the stopped state. The next instruction is initiated by clocking a "1" into the flip-flop. This "1" will not appear on SS' unless ALE is high removing clear from the flip-flop. In response to SS' going high the processor begins an instruction fetch which brings ALE low resetting SS' through the clear input and causing the processor to again enter the stopped state.

## 2.14 Power Down Mode

(8048AH, 8049AH, 8050AH,

## 8039AHL, 8035AHL, 8040AHL)

Extra circuitry has been added to the 8048AH/8049AH/ 8050AH ROM version to allow power to be removed from all but the data RAM array for low power standby operation. In the power down mode the contents of data RAM can be maintained while drawing typically 10% to 15% of normal operating power requirements.

VCC serves as the 5V supply pin for the bulk of circuitry while the VDD pin supplies only the RAM array. In normal operation both pins are at 5V while in standby, VCC is at ground and VDD is maintained at its standard value. Applying Reset to the processor through the RESET' pin inhibits any access to the RAM by the processor and guarantees the RAM cannot be inadvertently altered as power is removed from VCC.

A typical power down sequence (17) occurs as follows:

1) Imminent power supply failure is detected by user defined circuitry. Signal must be early enough to allow 8048AH to save all necessary data before VCC falls below normal operating limits.
2) Power fail signal is used to interrupt processor and vector it to a power fail service routine.
3) Power fail routine saves all important data and machine status in the internal data RAM array. Routine may also initiate transfer of backup supply to the VDD pin and indicate to external circuitry that power fail routine is complete.
4) Reset is applied to guarantee data will not be altered as the power supply falls out of limits. Reset must be held low until VCC is at ground level.

Recovery from the Power Down mode can occur as any other power-on sequence with an external capacitor on the Reset input providing the necessary delay. See the previous section on Reset.

16

Figure 15.

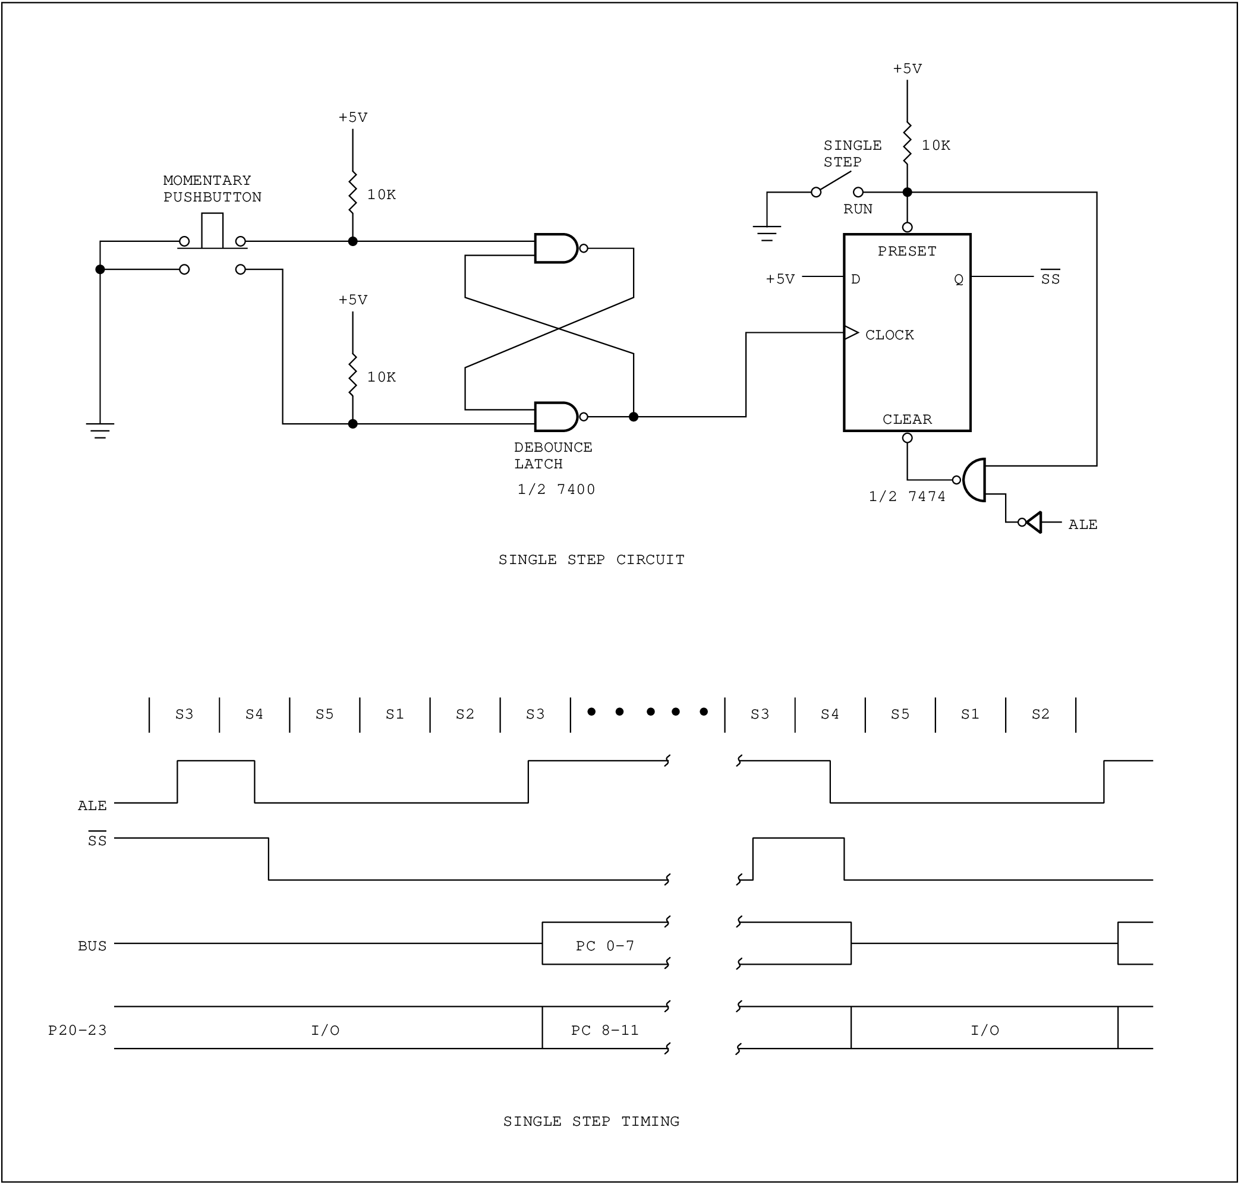
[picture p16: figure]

17

Figure 16. Single Step Operation

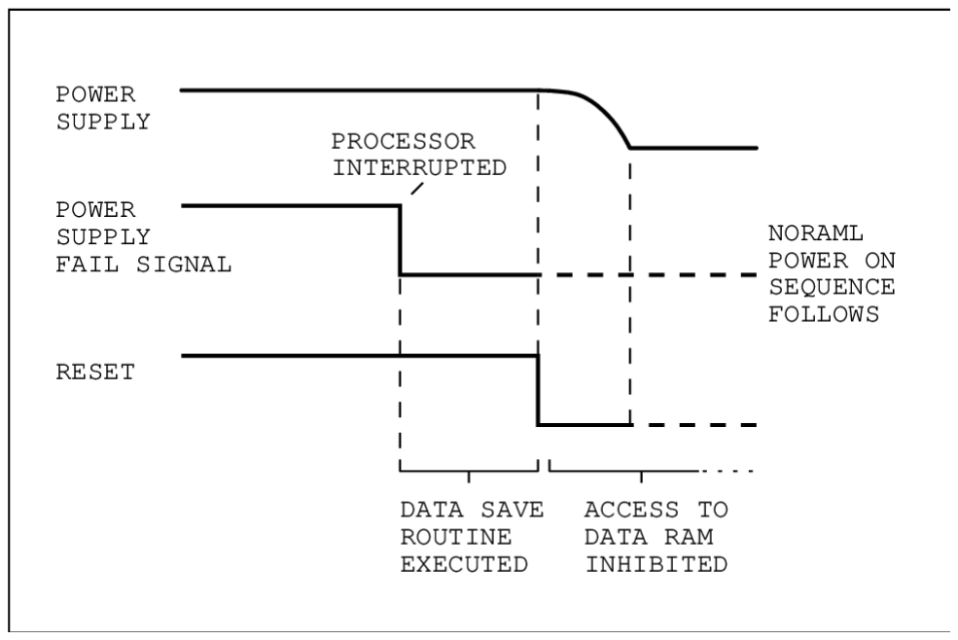
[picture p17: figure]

## 2.15 External Access Mode

Normally, the first 1K (8048AH), 2K (8049AH) or 4K (8050AH) words of program memory are automatically fetched from internal ROM or EPROM. The EA input pin however allows the user to efficiently disable internal program memory by forcing all program memory fetches to reference external memory. The following chapter explains how access to external program memory is accomplished.

The External Access mode is very useful in system test and debug because it allows the user to disable his internal applications program and substitute an external program of his choice --- a diagnostic routine for instance. In addition, the data sheet shows how internal program memory can be read externally, independent of the processor. A "1" level on EA initiates the external access mode. For proper operation, Reset should be applied while the EA input is changed.

## 2.16 Sync Mode

The 8048AH, 8049AH, 8050AH has incorporated a new SYNC mode. The Sync mode is provided to ease the design of multiple controller circuits by allowing the designer to force the device into known phase and state time. The SYNC mode may also be utilized by automatic test equipment (ATE) for quick, easy and efficient synchronizing between the tester and the DUT (device under test).

SYNC mode is enabled when SS' pin is raised to high voltage level of +12 volts. To begin synchronization, T0 is raised to 5 volts at least four clock cycles after SS'. T0 must be high for at least four X1 clock cycles to fully reset the prescaler and time state generators. T0 may then be brought down with the rising edge of X1. Two clock cycles later, with the rising edge of X1, the device enters into Time State 1, Phase 1. SS' is then brought down to 5 volts

4 clocks later after T0. RESET' is allowed to go high 5 tCY (75 clocks) later for normal execution of code. See 18.

18

Figure 17. Power Down Sequence

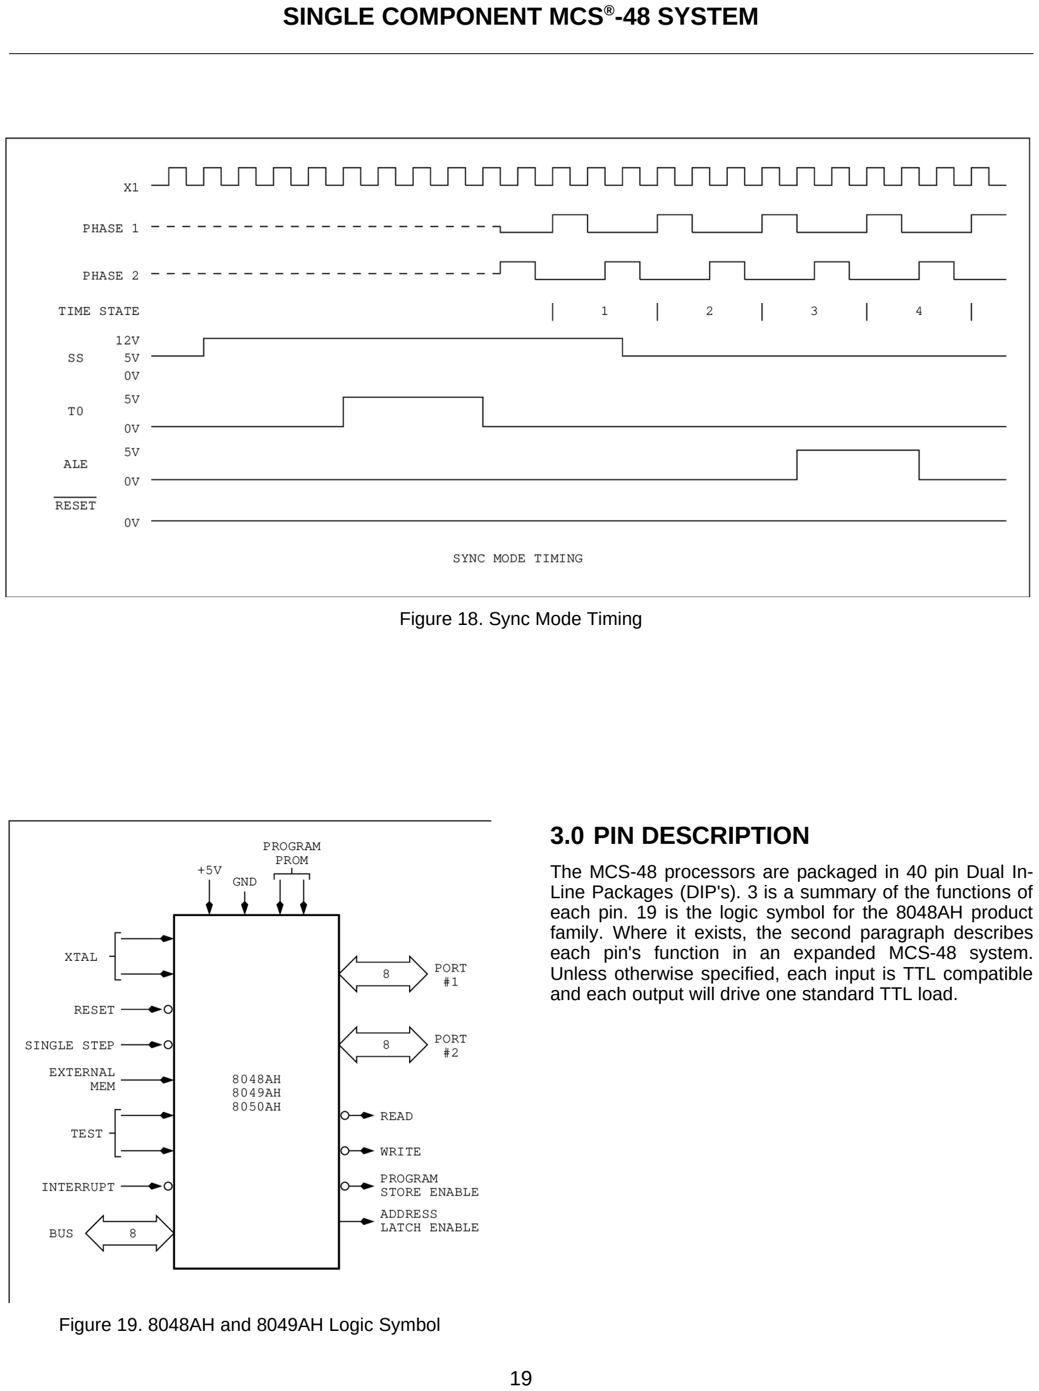
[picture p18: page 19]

## 3.0 PIN DESCRIPTION

The MCS-48 processors are packaged in 40 pin Dual In-Line Packages (DIP's). 3 is a summary of the functions of each pin. 19 is the logic symbol for the 8048AH product family. Where it exists, the second paragraph describes each pin's function in an expanded MCS-48 system. Unless otherwise specified, each input is TTL compatible and each output will drive one standard TTL load.

19

Figure 19. 8048AH and 8049AH Logic Symbol

Figure 18. Sync Mode Timing

20

Table 3. Pin Description

Designation

Pin
| Number* | Function
VSS | 20 | Circuit GND potential
VDD | 26 | Programming power supply; 21V during program for the 8748H/8749H; +5V during
| | operation for both ROM and EPROM. Low power standby pin in 8048AH and
| | 8049AH/8050AH ROM versions.
VCC | 40 | Main power supply; +5V during operation and during 8748H and 8749H programming.
PROG | 25 | Program pulse; +18V input pin during 8748H/8749H programming. Output strobe for 8243
| | I/O expander.
P10-P17 (Port 1) | 27-34 | 8-bit quasi-bidirectional port. (Internal Pullup ≈ 50 kΩ)
P20-27 (Port 2) | 21-24
| 35-38 | 8-bit quasi-bidirectional port. (Internal Pullup ≈ 50 kΩ)
| | P20-23 contain the four high order program counter bits during an external program mem-
| | ory fetch and serve as a 4-bit O/O expander bus for 8243.
D0-D7 (BUS) | 12-19 | True bidirectional port which can be written or read synchronously using the RD', WR'
| | strobes. The port can also be statically latched.
| | Contains the 8 low order program counter bits during an external program memory fetch,
| | and receives the addressed instruction under the control of PSEN'. Also contains the
| | address and data during an external RAM data store instruction, under control of ALE, RD'
| | and WR'.
T0 | 1 | Input pin testable using the conditional transfer instructions JT0 and JNT0. T0 can be des-
| | ignated as a clock output using ENT0 CLK instruction. T0 is also used during programming
| | and sync mode.
T1 | 39 | Input pin testable using the JT1 and JNT1 instructions. Can be designated the event
| | counter input using the STRT CNT instruction. (See Section 2.10).
INT' | 6 | Interrupt input. Initiates an interrupt if interrupt is enabled. Interrupt is disabled after a reset.
| | (Active low)
| | Interrupt must remain low for at least 3 machine cycles to ensure proper operation.
RD' | 8 | Output strobe activated during a BUS read. Can be used to enable data onto the BUS from
| | external device. (Active low)
RESET' | 4 | Input which is used to initialize the processor. Also used during EPROM programming and
| | verification. (Active low) (Internal pullup ≈ 50 kΩ)
WR' | 10 | Output strobe during a BUS write. (Active low) Used as a write strobe to external data
| | memory.
ALE | 11 | Address Latch Enable. This signal occurs once during each cycle and is useful as a clock
| | output.
| | The negative edge of ALE strobes address into external data and program memory.
PSEN' | 9 | Program Store Enable. This output occurs only during a fetch to external program memory.
| | (Active low)
SS' | 5 | Single step input can be used in conjunction with ALE to "single step" the processor
| | through each instruction. (Active low) (Internal Pullup ≈ 300 kΩ) +12V for sync modes (See
| | Section 2.16).

## 4.0 PROGRAMMING, VERIFYING, AND ERASING EPROM

The internal Program Memory of the 8748H and the 8749H may be erased and reprogrammed by the user as explained in the following sections. See also the 8748H and 8749H data sheets.

## 4.1 Programming/Verification

In brief, the programming process consists of: applying the program mode, applying an address, latching the address, applying data, and applying a programming pulse. This programming algorithm applies to both the 8748H and 8749H. Each word is programmed completely before moving on to the next and is followed by a verification step. The following is a list of the pins used for programming and a description of their functions:

Pin | Function
XTAL1 | Clock Input (3 to 4.0 MHz)
Reset | Initialization and Address Latching
Test 0 | Selection of Program (0 V) or Verify (5 V) Mode
EA | Activation of Program/Verify Modes
BUS | Address and Data Input. Data Output During Verify
P20-1 | Address Input for 8748H
P20-2 | Address Input for 8749H
VDD | Programming Power Supply
PROG | Program Pulse Input
P10-P11 | Tied to ground (8749H only)

## 4.1.1 8748H and 8749H ERASURE CHARACTERISTICS

The erasure characteristics of the 8748H and 8749H are such that erasure begins to occur when exposed to light with wavelengths shorter than approximately 4000 Angstroms (Å). It should be noted that the sunlight and certain types of fluorescent lamps have wavelengths in the 3000-4000 Å range. Data show that constant exposure to room level fluorescent lighting could erase the typical 8748H and 8749H in approximately 3 years while it would take approximately 1 week to cause erasure when exposed to direct sunlight. If the 8748H or 8749H is to be exposed to these types of lighting conditions for extended periods of time, opaque labels should be placed over the 8748H window to prevent unintentional erasure.

When erased, bits of the 8748H and 8749H Program Memory are in the logic "0" state.

The recommended erasure procedure for the 8748H and 8749H is exposure to shortwave ultraviolet light which has a wavelength of 2537 Angstroms (Å). The integrated dose
(i. e., UV intensity × exposure time) for erasure should be a minimum of 15 Wsec/cm²

power rating. The 8748H and 8749H should be placed within one inch from the lamp tubes during erasure. Some lamps have a filter in their tubes and this filter should be removed before erasure.

21

Table 3. Pin Description (Continued)

Designation | Pin Number* | Function
EA XTAL1 XTAL2 | 7 2 3 | External Access input which forces all program memory fetches to reference external memory. Useful for emulation and debug and essential for testing and program verification. (Active high) +12V for 8048AH/8049AH/8050AH program verification and +18V for 8748H/8749H program verification (Internal Pullup ≈ 10 MΩ on 8048AH/8049AH/ 8035AHL/8039AHL/8050AH/8040AHL) One side of crystal input for internal oscillator. Also input for external source. Other side of crystal/external source input.

*Unless otherwise stated, inputs do not have internal pullup resistors. 8048AH, 8748H, 8049AH, 8050AH, 8040AHL

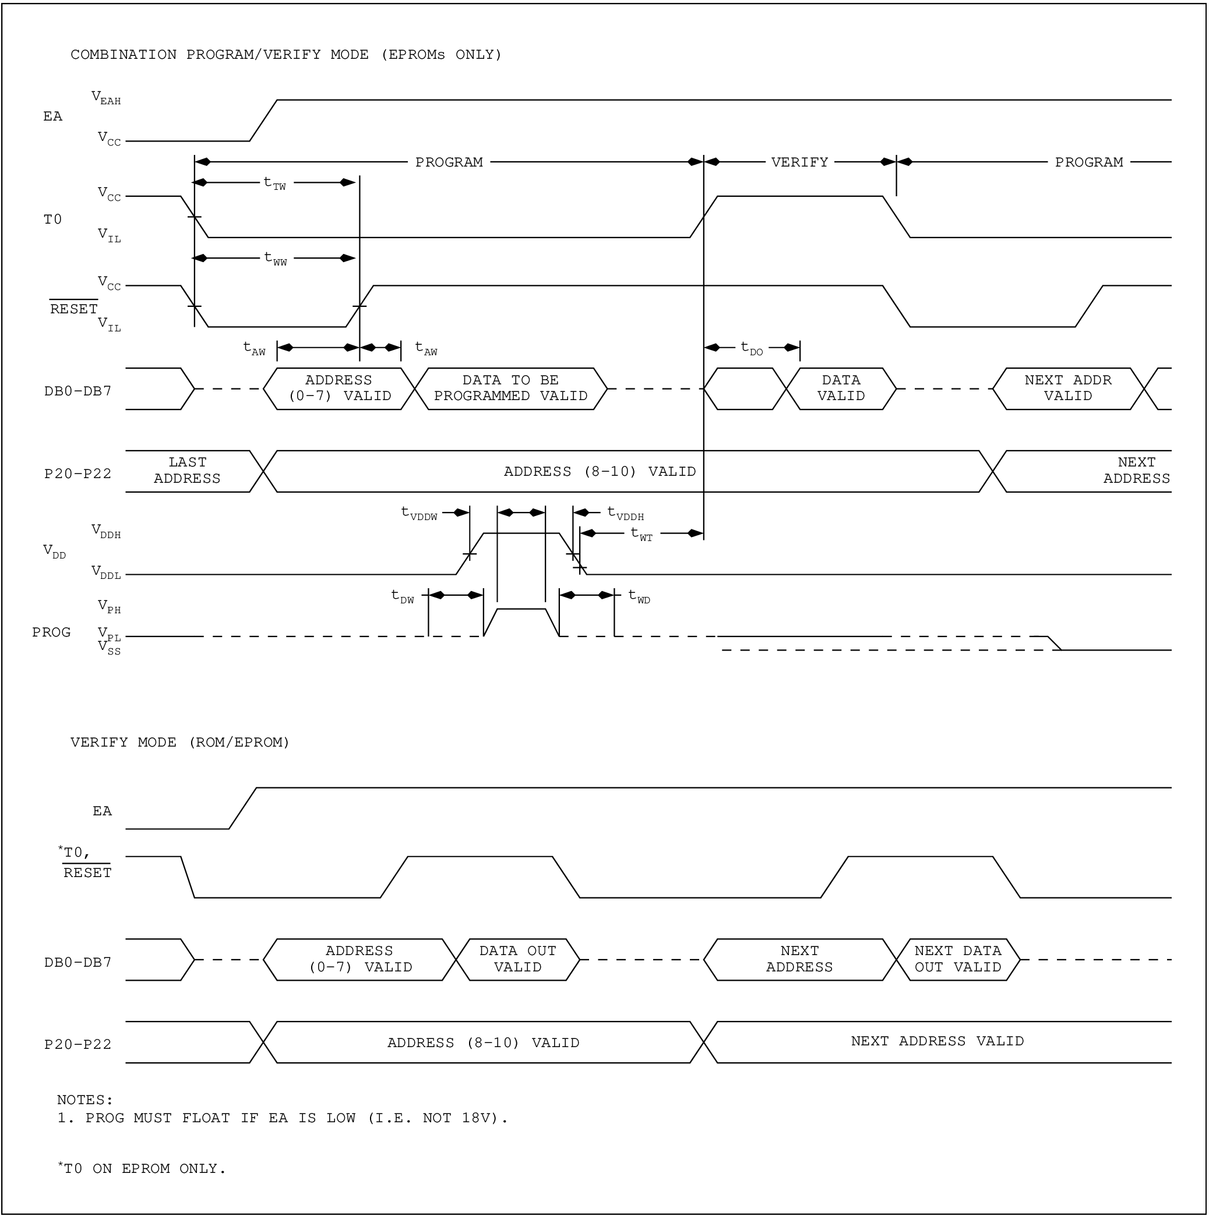
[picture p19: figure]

22

Figure 20. Program/Verify Sequence for 8749H/8748H

23

Table 4. A.C. Specification for Programming 8748H/8749H

Symbol | Parameter | Min | Max | Unit | Test Conditions
tAW | Address Setup Time to RESET' ↑ | 4tCY
tWA | Address Hold Time to RESET' ↑ | 4tCY
tDW | Data in Setup Time to PROG ↑ | 4tCY
tWD | Data in Hold Time after PROG ↓ | 4tCY
tPH | RESET' Hold Time to Verify | 4tCY
tVDDW | VDD Hold Time before PROG ↑ | 0 | 1.0 | ms
tVDDH | VDD Hold Time after PROG ↓ | 0 | 1.0 | ms
tPW | Program Pulse Width | 50 | 60 | ms
tTW | TEST 0 Setup Time for Program Mode | 4tCY
tWT | TEST 0 Hold Time after Program Mode | 4tCY
tDO | TEST 0 to data Out Delay | | 4tCY
tWW | RESET' Pulse Width to Latch Address | 4tCY
tr, tf | VDD and PROG Rise and Fall Times | 0.5 | 100 | µs
tCY | CPU Operation Cycle Time | 3.75 | 5 | µs
tRE | RESET' Setup Time before EA ↑ | 4tCY

TA = 25 °C; VCC = 5 V ±5%; VDD = 21 V ±5%

NOTE:
If TEST 0 is high, tDO can be triggered by RESET' ↑.

Table 5. D.C. Specification for Programming 8748H/8749H

Symbol | Parameter | Min | Max | Unit | Test Conditions
VDDH | VDD Program Voltage High Level | 20.5 | 21.5 | V
VDDL | VDD Voltage Low Level | 4.75 | 5.25 | V
VPH | PROG Program Voltage High Level | 17.5 | 18.5 | V
VPL | PROG Voltage Low Level | 4.0 | VCC | V
VEAH | EA Program or Verify Voltage High Level | 17.5 | 18.5 | V
IDD | VDD High Voltage Supply Current | | 20.0 | mA
IPROG | PROG High Voltage Supply Current | | 1.0 | mA
IEA | EA High Voltage Supply Current | | 1.0 | mA

TA = 25 °C; VCC = 5 V ±5%; VDD = 21 V ±5%

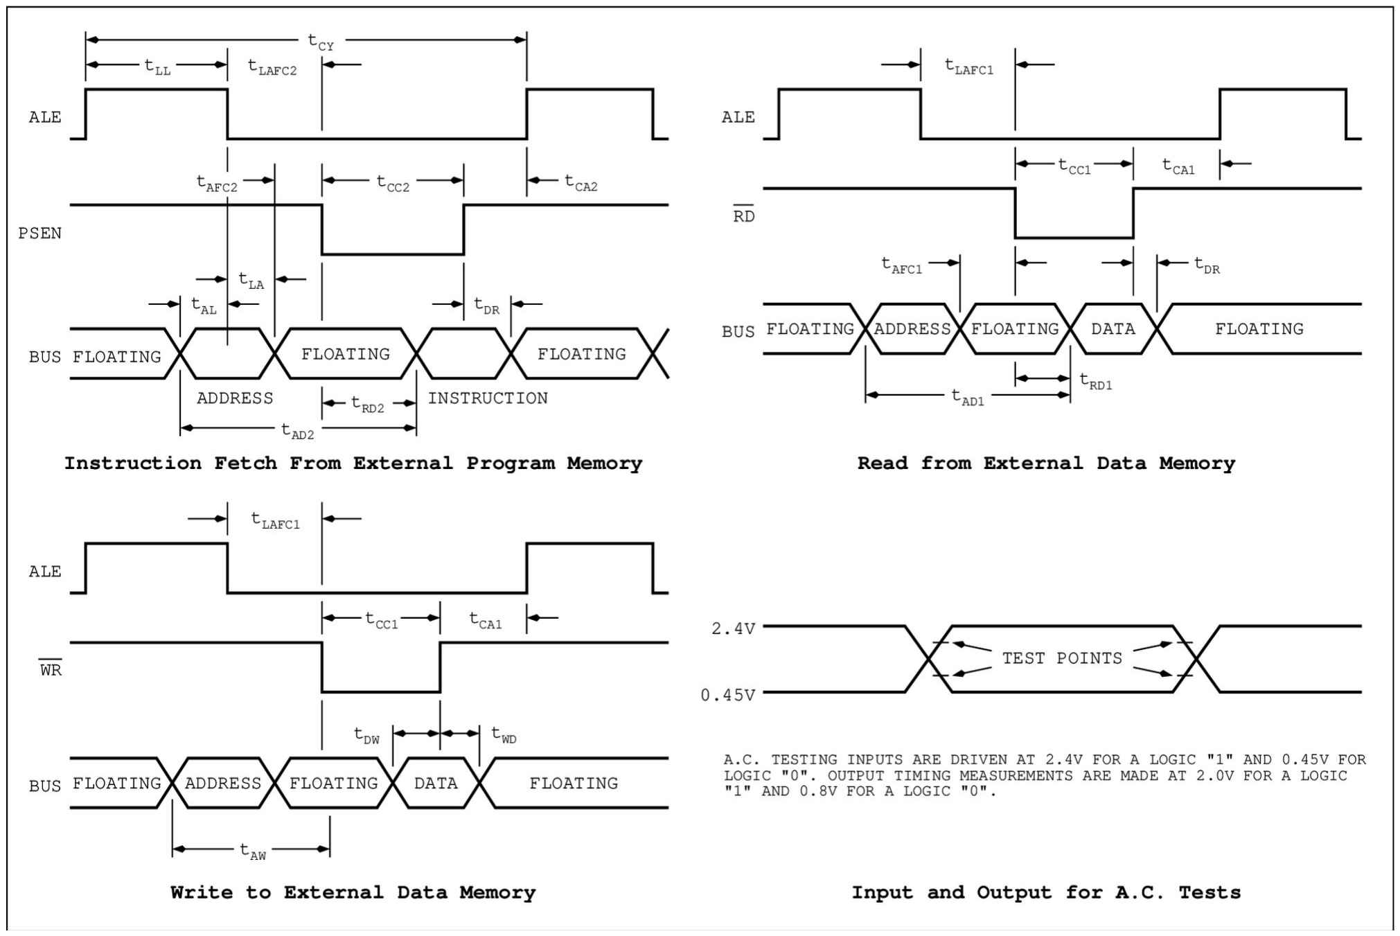
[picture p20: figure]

24

Figure 21. External Access Timing Waveforms

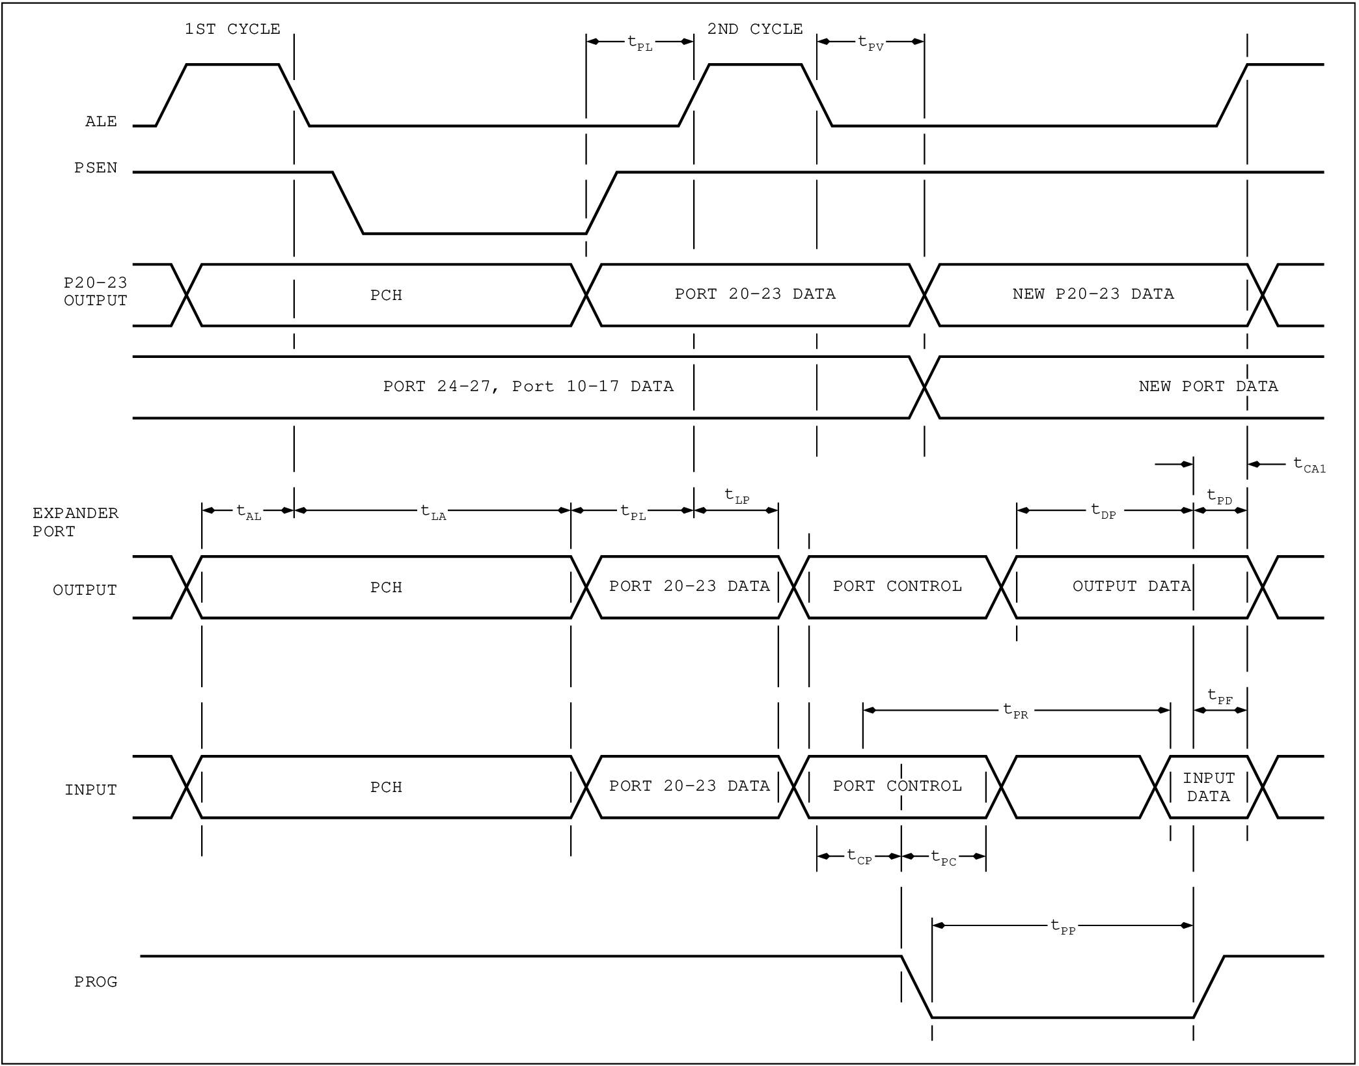
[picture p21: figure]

25

Figure 22. Port 1 / Port 2 Timing Waveforms

26

A.C. CHARACTERISTICS (TA = 0 °C to 70 °C; VCC = VDD = 5 V ± 10%; VSS = 0 V)

Symbol | Parameter | f (tCY) (Note 4) | 11 MHz | Unit | Conditions (Note 1)
Min | Max
tCY | Cycle Time | 15/F(XTAL) | 1.36 | 15.0 | us | (Note 3)
tLL | ALE Pulse Width | 7/30 tCY - 170 | 150 | | ns
tAL | Addr Setup to ALE | 2/15 tCY - 110 | 70 | | ns | (Note 2)
tLA | Addr Hold from ALE | 1/15 tCY - 40 | 50 | | ns
tCC1 | Control Pulse Width (RD', WR') | 1/2 tCY - 200 | 480 | | ns
tCC2 | Control Pulse Width (PSEN') | 2/5 tCY - 200 | 350 | | ns
tDW | Data Setup before WR' | 13/30 tCY - 200 | 390 | | ns
tWD | Data Hold after WR' | 1/15 tCY - 50 | 40 | | ns
tDR | Data Hold (RD', PSEN') | 1/10 tCY - 30 | 0 | 110 | ns
tRD1 | RD' to Data In | 11/30 tCY - 170 | | 330 | ns
tRD2 | PSEN' to Data In | 4/15 tCY - 170 | | 190 | ns
tAW | Addr Setup to WR' | 1/3 tCY - 150 | 300 | | ns
tAD1 | Addr Setup to Data (RD') | 7/10 tCY - 220 | | 730 | ns
tAD2 | Addr Setup to Data (PSEN') | 1/2 tCY - 220 | | 460 | ns
tAFC1 | Addr Float to RD', WR' | 2/15 tCY - 40 | 140 | | ns | (Note 2)
tAFC2 | Addr Float to PSEN' | 1/30 tCY - 40 | 10 | | ns | (Note 2)
tLAFC1 | ALE to Control (RD', WR') | 1/5 tCY - 75 | 200 | | ns
tLAFC2 | ALE to Control (PSEN') | 1/10 tCY - 75 | 60 | | ns
tCA1 | Control to ALE (RD', WR', PROG') | 1/15 tCY - 40 | 50 | | ns
tCA2 | Control to ALE (PSEN') | 4/15 tCY - 40 | 320 | | ns
tCP | Port Control Setup to PROG' | 2/15 tCY - 80 | 100 | | ns
tPC | Port Control Hold to PROG' | 4/15 tCY - 200 | 160 | | ns
tPR | PROG' to P2 Input Valid | 17/30 tCY - 120 | | 650 | ns
tPF | Input Data Hold from PROG' | 1/10 tCY | 0 | 140 | ns
tDP | Output Data Setup | 2/5 tCY - 150 | 400 | | ns
tPD | Output Data Hold | 1/10 tCY - 50 | 90 | | ns
tPP | PROG' Pulse Width | 7/10 tCY - 250 | 700 | | ns
tPL | Port 2 I/O Setup to ALE | 4/15 tCY - 200 | 160 | | ns
tLP | Port 2 I/O Hold to ALE | 1/30 tCY - 30 | 15 | | ns
tPV | Port Output from ALE | 3/10 tCY + 100 | | 510 | ns
t0PRR | T0 Rep Rate | 3/15 tCY | 270 | | ns

Notes:
1. Control output CL = 80 pF
BUS Outputs CL = 150 pF
2. BUS High Impedance
Load 20 pF
3. f(tCY) assumes 50% duty cycle on X1 and X2.

27

Instruction Code | Flags
Mnemonic | Function | Description | D7 | D6 | D5 | D4 | D3 | D2 | D1 | D0 | Cycles | Bytes | C | AC F0 | F1
| | | Data Moves
MOV A, = data | (A) ← data | Move immediate the specified data into the Accumulator. | 0 d7 | 0 d6 | 1 d5 | 0 d4 | 0 d3 | 0 d2 | 1 d1 | 1 d0 | 2 | 2
MOV A, Rr | (A) ← (Rr); r = 0 – 7 | Move the contents of the designated register into the Accumulator. | 1 | 1 | 1 | 1 | 1 | r | r | r | 1 | 1
MOV A, @ Rr | (A) ← ((Rr)); r = 0 – 1 | Move indirect the contents of data memory location into the Accumulator. | 1 | 1 | 1 | 1 | 0 | 0 | 0 | r | 1 | 1
MOV A, PSW | (A) ← (PSW) | Move contents of the Program Status Word into the Accumulator. | 1 | 1 | 0 | 0 | 0 | 1 | 1 | 1 | 1 | 1
MOV Rr, = data | (Rr) ← data; r = 0 – 7 | Move immediate the specified data into the designated register. | 1 d7 | 0 d6 | 1 d5 | 1 d4 | 1 d3 | r d2 | r d1 | r d0 | 2 | 2
MOV Rr, A | (Rr) ← (A); r = 0 – 7 | Move Accumulator contents into the designated register. | 1 | 0 | 1 | 0 | 1 | r | r | r | 1 | 1
MOV @ Rr, A | ((Rr)) ← (A); r = 0 – 1 | Move indirect Accumulator contents into data memory location. | 1 | 0 | 1 | 0 | 0 | 0 | 0 | r | 1 | 1
MOV @ Rr, = data ((Rr)) ← data; r = 0 – 1 | Move immediate the specified data into
data memory.
| | | 1 d7 | 0 d6 | 1 d5 | 1 d4 | 0 d3 | 0 d2 | 0 d1 | r d0 | 2 | 2
MOV PSW, A | (PSW) ← (A) | Move contents of Accumulator into the Program Status Word. | 1 | 1 | 0 | 1 | 0 | 1 | 1 | 1 | 1 | 1
MOVP A, @ A | (PC 0 – 7) ← (A)
(A) ← ((PC))
| | Move data in the current page into the
Accumulator.
| | | 1 | 0 | 1 | 0 | 0 | 0 | 1 | 1 | 2 | 1
MOVP3 A, @ A | (PC 0 – 7) ← (A) (PC 8 – 10) ← 011
(A) ← ((PC))
| | Move Program data in Page 3 into the
Accumulator.
| | | 1 | 1 | 1 | 0 | 0 | 0 | 1 | 1 | 2 | 1
MOVX A, @ Rr | (A) ← ((Rr)); r = 0 – 1 | Move indirect the contents of external data memory into the Accumulator. | 1 | 0 | 0 | 0 | 0 | 0 | 0 | r | 2 | 1
MOVX @ Rr, A | ((Rr)) ← (A); r = 0 – 1 | Move indirect the contents of the Accumulator into external data memory. | 1 | 0 | 0 | 1 | 0 | 0 | 0 | r | 2 | 1
XCH A, Rr | (A) | (Rr); r = 0 – 7 ⇄ | Exchange the Accumulator and
| | designated register's contents. | 0 | 0 | 1 | 0 | 1 | r | r | r | 1 | 1
XCH A, @ Rr | (A) | ((Rr)); r = 0 – 1 ⇄ | Exchange indirect contents of Accumu-
| | lator and location in data memory. | 0 | 0 | 1 | 0 | 0 | 0 | 0 | r | 1 | 1
XCHD A, @ Rr | (A 0 – 3) | ((Rr)(0 – 3)) ⇄
| r = 0 – 1 | Exchange indirect 4-bit contents of Accumulator and data memory. | 0 | 0 | 1 | 1 | 0 | 0 | 0 | r | 1 | 1
| | | Flags
CPL C | (C) ← NOT (C) | Complement content of carry bit. | 1 | 0 | 1 | 0 | 0 | 1 | 1 | 1 | 1 | 1 | •
CPL F0 | (F0) ← NOT (F0) | Complement content of Flag F0. | 1 | 0 | 0 | 1 | 0 | 1 | 0 | 1 | 1 | 1 | •
CPL F1 | (F1) ← NOT (F1) | Complement content of Flag F1. | 1 | 0 | 1 | 1 | 0 | 1 | 0 | 1 | 1 | 1 | •
CLR C | (C) ← 0 | Clear content of carry bit to 0. | 1 | 0 | 0 | 1 | 0 | 1 | 1 | 1 | 1 | 1 | •
CLR F0 | (F0) ← 0 | Clear content of Flag 0 to 0. | 1 | 0 | 0 | 0 | 0 | 1 | 0 | 1 | 1 | 1 | •
CLR F1 | (F1) ← 0 | Clear content of Flag 1 to 0. | 1 | 0 | 1 | 0 | 0 | 1 | 0 | 1 | 1 | 1 | •

28

Instruction Code | Flags
Mnemonic | Function | Description | D7 | D6 | D5 | D4 | D3 | D2 | D1 | D0 | Cycles | Bytes | C | AC F0 | F1
| | | Input/Output
ANL BUS, = data | (BUS) ← (BUS) AND data | Logical and immediate specified data with contents on BUS. | 1 d7 | 0 d6 | 0 d5 | 1 d4 | 1 d3 | 0 d2 | 0 d1 | 0 d0 | 2 | 2
ANL Pp, = data | (Pp) ← (Pp) AND data
p = 1 – 2
| | Logical and immediate specified data with designated port (1 – 2). | 1 d7 | 0 d6 | 0 d5 | 1 d4 | 1 d3 | 0 d2 | p d1 | p d0 | 2 | 2
ANLD Pp, A | (Pp) ← (Pp) AND (A 0 – 3)
p = 4 – 7
| | Logical and contents of Accumulator with designated port (4 – 7). | 1 | 0 | 0 | 1 | 1 | 1 | p | p | 2 | 1
IN A, Pp | (A) ← (Pp); p = 1 – 2 | Input data from designated port (1 – 2) into Accumulator. | 0 | 0 | 0 | 0 | 1 | 0 | p | p | 2 | 1
INS A, BUS | (A) ← (BUS) | Input strobed BUS data into Accumulator. | 0 | 0 | 0 | 0 | 1 | 0 | 0 | 0 | 2 | 1
MOVD A ,Pp | (A 0 – 3) ← (Pp); p = 4 – 7 (A 4 – 7) ← 0 | Move contents of designated port (4 – 7) into Accumulator. | 0 | 0 | 0 | 0 | 1 | 1 | p | p | 2 | 1
MOVD Pp, A | (Pp) ← A (0 – 3); p = 4 – 7 | Move contents of Accumulator to designated port (4 – 7). | 0 | 0 | 1 | 1 | 1 | 1 | p | p | 2 | 1
ORL BUS, = data | (BUS) ← (BUS) OR data | Logical or immediate specified data with contents of BUS. | 1 d7 | 0 d6 | 0 d5 | 0 d4 | 1 d3 | 0 d2 | 0 d1 | 0 d0 | 2 | 2
ORLD Pp, A | (Pp) ← (Pp) OR (A 0 – 3)
p = 4 – 7
| | Logical or contents of Accumulator with designated port (4 – 7). | 1 | 0 | 0 | 0 | 1 | 1 | p | p | 2 | 1
ORL Pp, = data | (Pp) ← (Pp) OR data
p = 1 – 2
| | Logical or immediate specified data with designated port (1 – 2). | 1 d7 | 0 d6 | 0 d5 | 0 d4 | 1 d3 | 0 d2 | p d1 | p d0 | 2 | 2
OUTL BUS, A ⑤ | (BUS) ← A | Output contents of Accumulator onto
BUS.
| | | 0 | 0 | 0 | 0 | 0 | 0 | 1 | 0 | 2 | 1
OUTL Pp, A | (Pp) ← (A); p = 1 – 2 | Output contents of Accumulator to designated port (1 – 2). | 0 | 0 | 1 | 1 | 1 | 0 | p | p | 2 | 1
| | | Registers
DEC Rr | (Rr) ← (Rr) – 1; r = 0 – 7 | Decrement by 1 contents of designated
register.
| | | 1 | 1 | 0 | 0 | 1 | r | r | r | 1 | 1
INC Rr | (Rr) ← (Rr) + 1; r = 0 – 7 | Increment by 1 contents of designated
register.
| | | 0 | 0 | 0 | 1 | 1 | r | r | r | 1 | 1
INC @ Rr | ((Rr)) ← ((Rr)) + 1; r = 0 – 1 Increment indirect by 1 the contents of
| | data memory location. | 0 | 0 | 0 | 1 | 0 | 0 | 0 | r | 1 | 1
| | | Subroutine
CALL addr | ((SP)) ← (PC), (PSW 4 – 7) (SP) ← (SP) + 1 (PC 8 – 10) ← addr 8 – 10 (PC 0 – 7) ← addr 0 – 7 (PC 11) ← DBF | Call designated Subroutine. | a10 a7 | a9 a6 | a8 a5 | 1 a4 | 0 a3 | 1 a2 | 0 a1 | 0 a0 | 2 | 2
RET | (SP) ← (SP) – 1
(PC) ← ((SP))

Return from Subroutine without restoring Program Status Word.

1 | 0 | 0 | 0 | 0 | 0 | 1 | 1 | 2 | 1
RETR | (SP) ← (SP) – 1
(PC) ← ((SP))
(PSW 4 – 7) ← ((SP))

Return from Subroutine restoring Program Status Word.

1 | 0 | 0 | 1 | 0 | 0 | 1 | 1 | 2 | 1

Timer/Counter

EN TCNTI | Enable internal interrupt Flag for Timer/Counter output. | 0 | 0 | 1 | 0 | 0 | 1 | 0 | 1 | 1 | 1
DIS TCNTI | Disable internal interrupt Flag for Timer Counter output. | 0 | 0 | 1 | 1 | 0 | 1 | 0 | 1 | 1 | 1
MOV A, T | (A) ← (T) | Move contents of Timer/Counter into
| Accumulator. | 0 | 1 | 0 | 0 | 0 | 0 | 1 | 0 | 1 | 1
MOV T, A | (T) ← (A) | Move contents of Accumulator into
| Timer/Counter. | 0 | 1 | 1 | 0 | 0 | 0 | 1 | 0 | 1 | 1
STOP TCNT | Stop Count for Event Counter. | 0 | 1 | 1 | 0 | 0 | 1 | 0 | 1 | 1 | 1
STRT CNT | Start Count for Event Counter. | 0 | 1 | 0 | 0 | 0 | 1 | 0 | 1 | 1 | 1
STRT T | Start Count for Timer. | 0 | 1 | 0 | 1 | 0 | 1 | 0 | 1 | 1 | 1

29

Instruction Code | Flags
Mnemonic | Function | Description | D7 | D6 | D5 | D4 | D3 | D2 | D1 | D0 | Cycles | Bytes | C | AC F0 | F1
| | | Miscellaneous
NOP | | No Operation performed. | 0 | 0 | 0 | 0 | 0 | 0 | 0 | 0 | 1 | 1
| | | Accumulator
ADD A, = data | (A) ← (A) + data | Add immediate the specified Data to the
Accumulator.
| | | 0 d7 | 0 d6 | 0 d5 | 0 d4 | 0 d3 | 0 d2 | 1 d1 | 1 d0 | 2 | 2 | • | •
ADD A, Rr | (A) ← (A) + (Rr)
r = 0 – 7
| | Add contents of designated register to the Accumulator. | 0 | 1 | 1 | 0 | 1 | r | r | r | 1 | 1 | • | •
ADD A, @ Rr | (A) ← (A) + ((Rr))
r = 0 – 1
| | Add indirect the contents of the data memory location to the Accumulator. | 0 | 1 | 1 | 0 | 0 | 0 | 0 | r | 1 | 1 | • | •
ADDC A, = data | (A) ← (A) + (C) + data | Add immediate with carry the specified data to the Accumulator. | 0 d7 | 0 d6 | 0 d5 | 1 d4 | 0 d3 | 0 d2 | 1 d1 | 1 d0 | 2 | 2 | • | •
ADDC A, Rr | (A) ← (A) + (C) + (Rr)
r = 0 – 7
| | Add with carry the contents of the designated register to the Accumulator. | 0 | 1 | 1 | 1 | 1 | r | r | r | 1 | 1 | • | •
ADDC A, @ Rr | (A) ← (A) + (C) + ((Rr))
r = 0 – 1
| | Add indirect with carry the contents of data memory location to the Accumulator. | 0 | 1 | 1 | 1 | 0 | 0 | 0 | r | 1 | 1 | • | •
ANL A, = data | (A) ← (A) AND data | Logical and specified immediate data with Accumulator. | 0 d7 | 1 d6 | 0 d5 | 1 d4 | 0 d3 | 0 d2 | 1 d1 | 1 d0 | 2 | 2
ANL A, Rr | (A) ← (A) AND (Rr)
r = 0 – 7
| | Logical and contents of designated register with Accumulator. | 0 | 1 | 0 | 1 | 1 | r | r | r | 1 | 1
ANL A, @ Rr | (A) ← (A) AND ((Rr))
r = 0 – 1
| | Logical and indirect the contents of data memory with Accumulator. | 0 | 1 | 0 | 1 | 0 | 0 | 0 | r | 1 | 1
CPL A | (A) ← NOT (A) | Complement the contents of the
Accumulator.
| | | 0 | 0 | 1 | 1 | 0 | 1 | 1 | 1 | 1 | 1
CLR A | (A) ← 0 | CLEAR the contents of the Accumulator. | 0 | 0 | 1 | 0 | 0 | 1 | 1 | 1 | 1 | 1
DA A | | DECIMAL ADJUST the contents of the
Accumulator.
| | | 0 | 1 | 0 | 1 | 0 | 1 | 1 | 1 | 1 | 1 | •
DEC A | (A) ← (A) – 1 | Decrement by 1 the Accumulator's
contents.
| | | 0 | 0 | 0 | 0 | 0 | 1 | 1 | 1 | 1 | 1
INC A | (A) ← (A) + 1 | Increment by 1 the Accumulator's
contents.
| | | 0 | 0 | 0 | 1 | 0 | 1 | 1 | 1 | 1 | 1
ORL A, = data | (A) ← (A) OR data | Logical or specified immediate data with Accumulator. | 0 d7 | 1 d6 | 0 d5 | 0 d4 | 0 d3 | 0 d2 | 1 d1 | 1 d0 | 2 | 2
ORL A, Rr | (A) ← (A) OR (Rr)
r = 0 – 7
| | Logical or contents of designated register with Accumulator. | 0 | 1 | 0 | 0 | 1 | r | r | r | 1 | 1
ORL A, @ Rr | (A) ← (A) OR ((Rr))
r = 0 – 1
| | Logical or indirect the contents of data memory with Accumulator. | 0 | 1 | 0 | 0 | 0 | 0 | 0 | r | 1 | 1
RL A | (AN + 1) ← (AN); N = 0 – 6 (A0) ← (A7) | Rotate Accumulator left by 1-bit without
carry.
| | | 1 | 1 | 1 | 0 | 0 | 1 | 1 | 1 | 1 | 1
RLC A | (AN + 1) ← (AN); N = 0 – 6 (A0) ← (C)
(C) ← (A7)
| | Rotate Accumulator left by 1-bit through
carry.
| | | 1 | 1 | 1 | 1 | 0 | 1 | 1 | 1 | 1 | 1 | •
RR A | (AN) ← (AN + 1); N = 0 – 6
(A7) ← (A0)

Rotate Accumulator right by 1-bit without carry.

0 | 1 | 1 | 1 | 0 | 1 | 1 | 1 | 1 | 1
RRC A | (AN ) ← (AN + 1); N = 0 – 6
(A7) ← (C)
(C) ← (A0)

Rotate Accumulator right by 1-bit through carry.

0 | 1 | 1 | 0 | 0 | 1 | 1 | 1 | 1 | 1 | •
SWAP A | (A4 – 7) ⇄ (A0 – 3) | Swap the 2 4-bit nibbles in the
Accumulator.
0 | 1 | 0 | 0 | 0 | 1 | 1 | 1 | 1 | 1
XRL A, = data | (A) ← (A) XOR data | Logical xor specified immediate data
with Accumulator.
1 d7 | 1 d6 | 0 d5 | 1 d4 | 0 d3 | 0 d2 | 1 d1 | 1 d0 | 2 | 2
XRL A, Rr | (A) ← (A) XOR (Rr)
r = 0 – 7

Logical xor contents of designated register with Accumulator.

1 | 1 | 0 | 1 | 1 | r | r | r | 1 | 1
XRL A, @ Rr | (A) ← (A) XOR ((Rr))
r = 0 – 1

Logical xor indirect the contents of data memory with Accumulator.

1 | 1 | 0 | 1 | 0 | 0 | 0 | r | 1 | 1

30

Instruction Code | Flags
Mnemonic | Function | Description | D7 | D6 | D5 | D4 | D3 | D2 | D1 | D0 | Cycles | Bytes | C | AC F0 | F1
| | | Branch
DJNZ Rr, addr | (Rr) ← (Rr) – 1; r = 0 – 7 if (Rr) ≠ 0: (PcC0 – 7) ← addr | Decrement the specified register and
test contents.
| | | 1 a7 | 1 a6 | 1 a5 | 0 a4 | 1 a3 | r a2 | r a1 | r a0 | 2 | 2
JBb addr | (PC 0 – 7) ← addr if Bb = 1
(PC) ← (PC) + 2 if Bb = 0

Jump to specified address if Accumulator bit is set.

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
2 | 2
JC addr | (PC 0 – 7) ← addr if C = 1
(PC) ← (PC) + 2 if C = 0

Jump to specified address if carry flag is set.

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
2 | 2
JF0 addr | (PC 0 – 7) ← addr if F0 = 1
(PC) ← (PC) + 2 if F0 = 0

Jump to specified address if Flag F0 is set.

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
2 | 2
JF1 addr | (PC 0 – 7) ← addr if F01= 1
(PC) ← (PC) + 2 if F1 = 0

Jump to specified address if Flag F1 is set.

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
2 | 2
JMP addr | (PC 8 – 10) ← addr 8 – 10
(PC 0 -7) ← add 0 – 7
(PC 11) ← DBF

Direct Jump to specified address within the 2K address block.

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
2 | 2
JMPP @ A | (PC 0 – 7) ← ((A)) | Jump indirect to specified address within
address page.
| | 1 | 0 | 1 | 1 | 0 | 0 | 1 | 1 | 2 | 1
JNC addr | (PC 0 – 7) ← addr if C = 0
(PC) ← (PC) if C = 1
| Jump to specified address if carry flag is low. | 1 a7 | 1 a6 | 1 a5 | 0 a4 | 0 a3 | 1 a2 | 1 a1 | 0 a0 | 2 | 2
JNI addr | (PC 0 – 7) ← addr if I = 0
(PC) ← (PC) if I = 1
| Jump to specified address if interrupt is low. | 1 a7 | 0 a6 | 0 a5 | 0 a4 | 0 a3 | 1 a2 | 1 a1 | 0 a0 | 2 | 2
JNT0 addr | (PC 0 – 7) ← addr if T0 = 0
(PC) ← (PC) if T0 = 1
| Jump to specified address if Test 0 is low. | 0 a7 | 0 a6 | 1 a5 | 0 a4 | 0 a3 | 1 a2 | 1 a1 | 0 a0 | 2 | 2
JNT1 addr | (PC 0 – 7) ← addr if T1 = 0
(PC) ← (PC) if T1 = 1
| Jump to specified address if Test 1 is low. | 0 a7 | 1 a6 | 0 a5 | 0 a4 | 0 a3 | 1 a2 | 1 a1 | 0 a0 | 2 | 2
JNZ addr | (PC 0 – 7) ← addr if A ≠ 0
(PC) ← (PC) if A = 0
| Jump to specified address if Accumulator is non-zero. | 1 a7 | 0 a6 | 0 a5 | 1 a4 | 0 a3 | 1 a2 | 1 a1 | 0 a0 | 2 | 2
JTF addr | (PC 0 – 7) ← addr if TF = 1
(PC) ← (PC) if TF = 0
| Jump to specified address if Timer Flag is set to 1. | 0 a7 | 0 a6 | 0 a5 | 1 a4 | 0 a3 | 1 a2 | 1 a1 | 0 a0 | 2 | 2
JT0 addr | (PC 0 – 7) ← addr if T0 = 1
(PC) ← (PC) if T0 = 0
| Jump to specified address if Test 0 is a 1. | 0 a7 | 0 a6 | 1 a5 | 1 a4 | 0 a3 | 1 a2 | 1 a1 | 0 a0 | 2 | 2
JT1 addr | (PC 0 – 7) ← addr if T1 = 1
(PC) ← (PC) if T1 = 0
| Jump to specified address if Test 1 is a 1. | 0 a7 | 1 a6 | 0 a5 | 1 a4 | 0 a3 | 1 a2 | 1 a1 | 0 a0 | 2 | 2
JZ addr | (PC 0 – 7) ← addr if A = 0
(PC) ← (PC) if A ≠ 0
| Jump to specified address if Accumulator is 0. | 1 a7 | 1 a6 | 0 a5 | 0 a4 | 0 a3 | 1 a2 | 1 a1 | 0 a0 | 2 | 2
| | Control
EN I | Enable the external Interrupt input. | 0 | 0 | 0 | 0 | 0 | 1 | 0 | 1 | 1 | 1
DIS I | Disable the external Interrupt input. | 0 | 0 | 0 | 1 | 0 | 1 | 0 | 1 | 1 | 1
ENT0 CLK | Enable the Clock Output pin T0. | 0 | 1 | 1 | 1 | 0 | 1 | 0 | 1 | 1 | 1
SEL MB0 | (DBF) ← 0 | Select Bank 0 (locations 0 – 2047) of
| Program Memory. | 1 | 1 | 1 | 0 | 0 | 1 | 0 | 1 | 1 | 1
SEL MB1 | (DBF) ← 1 | Select Bank 1 (locations 2048 – 4095) of
| Program Memory. | 1 | 1 | 1 | 1 | 0 | 1 | 0 | 1 | 1 | 1
SEL RB0 | (BS) ← 0 | Select Bank 0 (locations 0 – 7) of
| Data Memory. | 1 | 1 | 0 | 0 | 0 | 1 | 0 | 1 | 1 | 1
SEL RB1 | (BS) ← 1 | Select Bank 1 (locations 24 – 31) of
| Data Memory. | 1 | 1 | 0 | 1 | 0 | 1 | 0 | 1 | 1 | 1

Notes: ① Instruction Code Designators r and p form the binary representation of the Registers and Ports involved.
② The dot under the appropriate flag bit indicates that its content is subject to change by the instruction it appears in.
③ References to the address and data are specified in bytes 2 and or 1 of the instruction.
④ Numerical Subscritions appearing in the FUNCTION column reference the specific bits affected.
⑤ When the Bus is written to with an OUTL instruction, the Bus remains an Output Port until either device is reset or a MOVX instruction is executed.

## 5.0 INSTRUCTION SET

The MCS-48 instruction set is extensive for a machine of its size and has been tailored to be straightforward and very efficient in its use of program memory. All instructions are either one or two bytes in length and over 70% are only one byte long. Also, all instructions execute in either one or two cycles (2.5 µsec or 5.0 µsec when using a 6 MHz XTAL) and over 50% of all instructions execute in a single cycle. Double cycle instructions include all immediate instructions and all I/O instructions.

The MCS-48 microcomputers have been designed to efficiently handle arithmetic operations in both binary and BCD as well as to efficiently handle the single bit operations required in control applications. Special instructions have also been included to simplify loop counters, table lookup routines, and N-way branch routines.

## Data Transfers

The 8-bit accumulator is the central point for all data transfers within the 8048. Data can be transferred between the 8 registers of each working register bank and the accumulator directly, i.e. The source or destination register is specified by the instruction. The remaining locations of the internal RAM array are referred to as Data Memory and are addressed indirectly via an address stored in either R0 or R1 of the active working register bank. R0 and R1 are also used to indirectly address external data memory when it is present. Transfers to and from internal RAM require one cycle while transfers to external RAM require two. Constants stored in Program Memory can be loaded directly to the accumulator and to the 8 working registers. Data can also be transferred directly between the on-board timer/counter or the accumulator and the Program Status Word (PSW). Writing to the PSW alters machine status accordingly and provides a means of restoring status after an interrupt or of altering the stack pointer if necessary.

## Accumulator Operations

Immediate data, data memory or the working registers can be added with or without carry to the accumulator. These sources can also be ANDed, ORed or Exclusive ORed to the accumulator. Data may be moved to or from the accumulator and working registers or data memory. The two values can also be exchanged in a single operation.

In addition, the lower 4 bits of the accumulator can be exchanged with the lower 4 bits of any of the internal RAM locations. This instruction, along with an instruction which swaps the upper and lower 4-bit halves of the accumulator, provides easy handling of 4-bit quantities, including BCD numbers. To facilitate BCD arithmetic, a Decimal Adjust instruction is included. This instruction is used to correct the result of the binary addition of two twodigit BCD numbers. Performing a decimal adjust on the result in the accumulator produces the required BCD result.

Finally, the accumulator can be: incremented, decremented, cleared or complemented and can be rotated left or right 1 bit at a time with or without carry.

Although there is no subtract instruction in the 8048, this operation can be easily implemented with three singlebyte single-cycle instructions.

A value may be subtracted from the accumulator with the result in the accumulator by:

Complement Accumulator CPL A
Add register to Accumulator ADD A, Rr Complement Accumulator CPL A

## Register Operations

The working registers can be accessed via the accumulator as explained above or can be loaded immediate with constraints from program memory. In addition, they can be incremented or decremented or used as loop counters using the decrement and skip, if not zero instruction, as explained under branch instructions.

All Data Memory including working registers can be accessed with indirect instructions via R0 and R1 and can be incremented.

## Flags

There are four user accessible flags in the 8048: Carry, Auxiliary Carry, F0, and F1. Carry indicates overflow of the accumulator and Auxiliary Carry is used to indicate overflow between BCD digits and is used during decimal adjust operation. Both Carry and Auxiliary Carry are accessible as part of the Program Status word and are stored on the stack during subroutines. F0 and F1 are undedicated general purpose flags to be used as the programmer desires. Both flags can be cleared or complemented and tested by conditional jump instructions. F0 is also accessible via the Program Status word and is stored on the stack with the carry flags.

## Branch Instructions

The unconditional jump instruction is two bytes and allows jumps anywhere in the first 2K words of program memory. Jumps to the second 2K of memory (4K words are directly addressable) are made by first executing a select memory bank instruction then executing the jump instruction. The 2K boundary can only be crossed via a jump or subroutine call instruction, i.e. The bank switch does not occur until a jump is executed. Once a memory bank has been selected all subsequent jumps will be to the selected bank until another select memory bank instruction is executed.

31

A subroutine in the opposite bank can be accessed by a select memory bank instruction followed by a call instruction. Upon completion of the subroutine execution will automatically return to the original bank; however, unless the original bank is reselected, the next jump instruction encountered will again transfer execution to the opposite bank.

Conditional jumps can test the following inputs and machine status:

T0 Input pin
T1 Input pin
INT' Input pin
Accumulator Zero
Any bit of Accumulator
Carry Flag
F0 Flag
F1 Flag

Conditional jumps allow a branch to any address within the current page (256 words) of execution. The conditions tested are the instantaneous values at the time the conditional jump is executed. For instance, the jump on accumulator zero instruction tests the accumulator itself not an intermediate zero flag.

The decrement register and skip if not zero instruction combines a decrement and a branch instruction to create an instruction very useful in implementing a loop counter. This instruction can designate any one of the 8 working registers as a counter and can effect a branch to any address within the current page of execution.

A single byte indirect jump instruction allows the program to be vectored to any one of several locations based on the contents of the accumulator. The contents of the accumulator points to a location in program memory which contains the jump address. The 8-bit jump address refers to the current page of execution. This instruction could be useful, for instance, to vector to any one of several routines based on an ASCII character which has been loaded in the accumulator. In this way ASCII key inputs can be used to initiate various routines.

## Subroutines

Subroutines are entered by executing a call instruction. Calls can be made like unconditional jumps to any address in a 2K word bank and jumps across the 2K boundary are executed in the same manner. Two separate return instructions determine whether or not status (upper 4 bits of PSW) is restored upon return from the subroutine.

The return and restore status instruction also signals the end of an interrupt service routine if one has been in progress.

## Timer Instructions

The 8-bit on board timer/counter can be loaded or read via the accumulator while the counter is stopped or while counting. The counter can be started as a timer with an internal clock source or as an event counter or timer with an external clock applied to the T1 input pin. The instruction executed determines which clock source is used. A single instruction stops the counter whether it is operating with an internal or an external clock source. In addition, two instructions allow the timer interrupt to be enabled or disabled.

## Control Instructions

Two instructions allow the external interrupt source to be enabled or disabled. Interrupts are initially disabled and are automatically disabled while an interrupt service routine is in progress and re-enabled afterwards.

There are four memory bank select instructions, two to designate the active working register bank and two to control program memory banks. The operation of the memory bank switch is explained in section 6.1.2. The working register bank switch instructions allow the programmer to immediately substitute a second 8 register working register bank for the one in use. This effectively provides 16 working registers or it can be used as a means of quickly saving the contents of the registers in response to an interrupt. The user has the option to switch or not to switch banks on interrupt. However, if the banks are switched, the original bank will be automatically restored upon execution of a return and restore status instruction at the end of the interrupt service routine.

A special instruction enables an internal clock, which is the XTAL frequency divided by three, to be output on pin T0. This clock can be used as a general purpose clock in the user system. This instruction should be used only to initialize the system since the clock output can be disabled only by application of system reset.

## Input/Output Instructions

Ports 1 and 2 are 8-bit static I/O ports which can be loaded to and from the accumulator. Outputs are statically latched but inputs are not latched and must be read while inputs are present. In addition, immediate data from program memory can be ANDed or ORed directly to Port 1 and Port 2 with the result remaining on the port. This allows “masks” stored in program memory to selectively set or reset individual bits of the I/O ports. Ports 1 and 2 are configured to allow input an a given pin by first writing a “1” out to th pin.

An 8-bit port called BUS can also be accessed via the accumulator and can have statically latched outputs as well. It too can have immediate data ANDed or ORed directly to its outputs, however, unlike Ports 1 and 2, all

32 eight lines of BUS must be treated as either input or output at any one time. In addition to being a static port, BUS can be used as a true synchronous bi-directional port using the Move External instructions used to access external data memory. When these instructions are executed a corresponding READ or WRITE pulse is generated and data is valid only at this time. When data is not being transferred BUS is in a high impedance state.

The basic three on board I/O ports can be expanded via a 4-bit expander bus using half of Port 2. I/O expander devices on this bus consist of four 4-bit ports which are addressed as ports 4 through 7. These ports have their own AND and OR instructions like the on board ports as well as move instructions to transfer data in and out. The expander AND and OR instructions, however, combine the contents of accumulator with the selected port rather than immediate data as is done with the on board ports.

I/O devices can also be added externally using the BUS port as the expansion bus. In this case the I/O ports become “memory mapped”, i.e. They are addressed in the same way as external data memory and exist in the external data memory address space addressed by pointer register R0 or R1.

## 5.1 Instruction Set Description

The following pages describe the MCS-48 instruction set in detail. The instruction set is first summarized with instructions grouped functionally. This summary page is followed by a detailed description listed alphabetically by mnemonic opcode.

The alphabetic listing includes the following information:

Mnemonic
Machine Code
Verbal Description
Symbolic Description

The machine code is represented with the most significant bit (7) to the left and two byte instructions are represented with the first byte on the left.

ADD A, Rr | Add Register Contents to Accumulator
(A) ← (A) + (Rr) | r = 0 – 7
The contents of register Rr is added to the Accumulator. The Carry flag is modified according to the result of the operation.
0 | 1 | 1 | 0 | 1 | r | r | r
ADD A, @ Rr | Add Data Memory Contents to Accumulator
(A) ← (A) + ((Rr)) | r = 0 – 1
The contents of the Data Memory location addressed by bits 0 – 5
(0 – 6 for 8039/8049) of register Rr is added to the Accumulator. The Carry flag is modified according to the result of the operation.
0 | 1 | 1 | 0 | 0 | 0 | 0 | r
ADD A, data | Add Immediate Data to Accumulator
(A) ← (A) + data | 2 cycles
The contents byte that follows the opcode is added to the Accumulator. The Carry flag is modified according to the result of the operation.
0 | 0 | 0 | 0 | 0 | 0 | 1 | 1
d7 | d6 | d5 | d4 | d3 | d2 | d1 | d0
ADDC A, Rr | Add Carry and Register Contents to Accumulator
(A) ← (A) + (C) + (Rr) | r = 0 – 7
The Carry flag is added to the Accumulator and then cleared. Afterwards, the contents of register Rr is added to the Accumulator. The Carry flag is modified according to the result of the operation.
0 | 1 | 1 | 1 | 1 | r | r | r
ADDC A, @ Rr | Add Carry and Data Memory Contents to
Accumulator
(A) ← (A) + (C) + ((Rr)) | r = 0 – 1
The Carry flag is added to the Accumulator and then cleared. Afterwards, the contents of the Data Memory location addressed by bits 0 – 5 (0 – 6 for 8039/8049) of register Rr is added to the Accumulator. The Carry flag is modified according to the result of the operation.
0 | 1 | 1 | 1 | 0 | 0 | 0 | r
ADDC A, data | Add Carry and Immediate Data to Accumulator
(A) ← (A) + (C) + data | 2 cycles
The Carry flag is added to the Accumulator and then cleared. Afterwards, the contents byte that follows the opcode is added to the Accumulator. The Carry flag is modified according to the result of the operation.
0 | 0 | 0 | 1 | 0 | 0 | 1 | 1
d7 | d6 | d5 | d4 | d3 | d2 | d1 | d0
ANL A, Rr | Logical AND Accumulator with Register Mask
(A) ← (A) ∧ (Rr) | r = 0 – 7
The contents of the Accumulator is logically (bitwise) anded with the contents of register Rr.
0 | 1 | 0 | 1 | 1 | r | r | r
ANL A, @ Rr | Logical AND Accumulator with Memory Mask
(A) ← (A) ((Rr)) ∧ | r = 0 – 1
The contents of the Accumulator is logically (bitwise) anded with the contents of the Data Memory location addressed by bits 0 – 5 (0 – 6 for 8039/8049) of register Rr.
0 | 1 | 0 | 1 | 0 | 0 | 0 | r

33

ANL A, data | Logical AND Accumulator with Immediate Mask
(A) ← (A) data ∧ | 2 cycles
The contents of the Accumulator is logically (bitwise) anded with the contents of the byte that follows the opcode.
0 1 0 1 | 0 0 1 1
d7 | d6 | d5 | d4 | d3 | d2 | d1 | d0
ANL BUS, data | Logical AND BUS with Immediate Mask
(BUS) ← (BUS) data ∧ | 2 cycles
BUS is read and its contents is logically (bitwise) anded with the contents of the byte that follows the opcode. This instruction requires the instruction OUTL BUS, A to be executed in advance.
Note: This instruction is not available for the 8021/8022. It must not be used with the 8035/8039 as BUS is used for external Program Memory access.
1 | 0 | 0 | 1 | 1 | 0 | 0 | 0
d7 | d6 | d5 | d4 | d3 | d2 | d1 | d0
ANL Pp, data | Logical AND Port 1 – 2 with Immediate Mask
(Pp) ← (Pp) data ∧ | p = 1 – 2 | 2 cycles
Port p is read and its contents is logically (bitwise) anded with the contents of the byte that follows the opcode.
Note: This instruction is not available for the 8021/8022.
1 0 0 1 | 1 0 p p
d7 d6 d5 d4 | d3 d2 d1 d0
ANLD Pp, A | Logical AND Port 4 – 7 with Accumulator Mask
(Pp) ← (Pp) A(0 – 3) ∧ | p = 4 – 7 | 2 cycles
Port p is read and its bits 0 – 3 are logically (bitwise) anded with bits 0 - 3 of the Accumulator.
1 | 0 | 0 | 1 | 1 | 1 | p | p | p | 1 – 0 | Port
| | | | | | | | | 0
| | | | | | | | | 0
| | | | | | | | | 1
| | | | | | | | | 1
| | | | | | | | | 0
| | | | | | | | | 1
| | | | | | | | | 0
| | | | | | | | | 1 | 4
| | | | | | | | | | 5
| | | | | | | | | | 6
| | | | | | | | | | 7
CALL addr | Subroutine Call

((SP)) ← (PC), (PSW 4 – 7)
(SP) ← (SP) + 1
(PC 8 – 10) ← addr 8 – 10
(PC 0 – 7) ← addr 0 – 7
(PC 11) ← DBF
| | | | | | | | | | 2 cycles

The Program Counter and bits 4 to 7 of the PSW are stored on the Program Stack. The Program Stack Counter (PSW 0 – 2) is updated. Program execution continues at the Program Memory location addressed by addr. Bit 11 of the Program Counter is initialized with DBF (determined by last SEL MBx instruction).
A CALL instruction cannot begin at Program Memory locations 2046-2047 or 4094-4095.
The program execution resumes with the next instruction after the CALL.
a10 | a9 | a8 | 1 | 0 | 1 | 0 | 0
a7 | a6 | a5 | a4 | a3 | a2 | a1 | a0
CLR A | Clear Accumulator
(A) ← 0
The contents of the Accumulator is cleared to 0.
0 | 0 | 1 | 0 | 0 | 1 | 1 | 1
CLR C | Clear Carry Bit
(C) ← 0
| The Carry bit is cleared to 0. The Carry bit can set by ADD, ADDC, RL C, CPL C, RRC an DAA.
1 0 0 1 | 0 1 1 1
CLR F0 | Clear Flag 0

(F0) ← 0
Flag 0 is cleared to 0.
Note: This instruction is not available for the 8021/8022.
1 | 0 | 0 | 0 | 0 | 1 | 0 | 1
CLR F1 | Clear Flag 1

(F1) ← 0
Flag 1 is cleared to 0.
Note: This instruction is not available for the 8021/8022.
1 | 0 | 1 | 0 | 0 | 1 | 0 | 1
CPL A | Complement Accumulator
(A) ← ¬ (A)
The contents of the Accumulator is inverted (one's complement).
0 | 0 | 1 | 1 | 0 | 1 | 1 | 1
CPL C | Complement Carry Bit
(C) ← ¬ (C)
The contents of the Carry bit is inverted.
1 | 0 | 1 | 0 | 0 | 1 | 1 | 1
CPL F0 | Complement Flag 0

(F0) ← ¬ (F0)
The contents of the Flag 0 is inverted.
Note: This instruction is not available for the 8021/8022.
1 | 0 | 0 | 1 | 0 | 1 | 0 | 1
CPL F1 | Complement Flag 1

(F1) ← ¬ (F1)
The contents of the Flag 1 is inverted.
Note: This instruction is not available for the 8021/8022.
1 | 0 | 1 | 1 | 0 | 1 | 0 | 1
DA A | Decimal Adjust Accumulator

The 8-bit value in the Accumulator is modified resulting in two BCD-encoded values.
1) If the value of bits 0 – 3 is greater than 9 or AC is set then 6 is added to the contents of the Accumulator.
2) If the value of bits 4 – 7 is now greater than 9 or C is set then 6 is added to the most significant nibble.
Example: The Accumulator contains 10011011.
C
0

0

1 | | AC
0

0

0

| | | 7
| | | 1
| | | 1
| | | 0
| | | 0 | 0
| | | | 0
| | | | 1
| | | | 0

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
| | | | | | 3
| | | | | | 1
| | | | | | 0
| | | | | | 0
| | | | | | 0 | 0
| | | | | | | 1
| | | | | | | 0
| | | | | | | 0

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
Add 6 to bits 0 – 7

Add 6 to bits 4 – 7
Overflow to Carry
0 | 1 | 0 | 1 | 0 | 1 | 1 | 1

34

DEC A | Decrement Accumulator
(A) ← (A) – 1
The contents of the Accumulator is decremented by 1.
0 | 0 | 0 | 0 | 0 | 1 | 1 | 1
DEC Rr | Decrement Register
(Rr) ← (Rr) – 1 | r = 0 – 1
The contents of register Rr is decremented by 1.
Note: This instruction is not available for the 8021/8022.
1 | 1 | 0 | 0 | 1 | r | r | r
DIS I | Disable External Interrupt

Disable external interrupt requests.
Note: This instruction is not available for the 8021.
0 | 0 | 0 | 1 | 0 | 1 | 0 | 1
DIS TCNTI | Disable Timer/Counter Interrupt

Disable Timer/Counter interrupt request. A pending interrupt request is cleared. Overflow of the counter does not trigger an interrupt, although the counter continues its operation and sets the T flag eventually.
Note: This instruction is not available for the 8021.
0 | 0 | 1 | 1 | 0 | 1 | 0 | 1
DJNZ Rr, addr | Decrement Register and Test

(Rr) ← (Rr) – 1
(PC 0 – 7) ← addr; if Rr ≠ 0
(PC) ← (PC) + 2; if Rr = 0
r = 0 – 7 | 2 cycles

The contents of register Rr is decremented by 1 and tested for zero. If all bits are 0 then program execution is continued with the next instruction. If not all bits are 0 then a jump to the given address is done. The address must be an 8-bit value, i. e. the jump will be within the current page (256 bytes). If the DJNZ instruction is at location 255 of a page then the jump destination will be located in the following page.
1 1 1 0 | 1 r r r
a7 | a6 | a5 | a4 | a3 | a2 | a1 | a0
EN I | Enable External Interrupt

Enable external interrupt request.
Note: This instruction is not available for the 8021.
0 | 0 | 0 | 0 | 0 | 1 | 0 | 1
EN TCNTI | Enable Timer/Counter Interrupt

Enable Timer/Counter interrupts request.
Note: This instruction is not available for the 8021.
0 | 0 | 1 | 0 | 0 | 1 | 0 | 1
ENT0 CLK | Enable Clock Output

Enables the clock output at T0 pin. A reset deactivates this function. Note: This instruction is not available for the 8021/8022.

0 | 1 | 1 | 1 | 0 | 1 | 0 | 1
IN A, Pp | Input Port or Data to Accumulator
(A) ← (Pp) | p = 1 – 2 | 2 cycles
Port p is read and its contents is stored in the Accumulator.
For the 8021 the instruction IN A, P2 triggers storing of P 20 – 23 to the Accumulator bits 0 – 3 (bits 4 – 7 are cleared to 0).
0 | 0 | 0 | 0 | 1 | 0 | p | p
INC A | Increment Accumulator
(A) ← (A) + 1
The contents of the Accumulator is incremented by 1.
0 | 0 | 0 | 1 | 0 | 1 | 1 | 1
INC Rr | Increment register
(Rr) ← (Rr) + 1 | r = 0 – 7
The contents of register Rr is incremented by 1.
0 | 0 | 0 | 1 | 1 | r | r | r
INC @ Rr | Increment Data Memory Location
((Rr)) ← ((Rr)) + 1 | r = 0 – 1
the contents of the Data Memory location addressed by bits 0 – 5 (0 – 6 for 8039/8049) of register Rr is incremented by 1.
0 | 0 | 0 | 1 | 0 | 0 | 0 | r
IN A, P0 | Input of Port 0 Data to Accumulator

Equivalent to INS A, BUS but not RD' strobe is generated. Note: This instruction is only available for the 8021/8022.

INS A, BUS | Strobed Input of BUS Data to Accumulator
(A) ← (BUS) | 2 cycles
BUS is read with a low-strobe on RD' and it contents is transferred to the Accumulator.
Note: This instruction must not be used with the 8035/8039 as BUS is used for external Program Memory access.
0 0 0 0 | 1 0 0 0
JBb addr | Jump if Accumulator Bit is Set

(PC 0 – 7) ← addr; if Bb = 1
(PC) ← (PC) + 2; if Bb = 0
b = 0 – 7 | 2 cycles

If Accumulator bit b is set then a jump is executed to the Program Memory location addressed by the byte that follows the opcode. If it is not set then program execution continues with the next instruction. Note: This instruction is not available for the 8021/8022.

b2 | b1 | b0 | 1 | 0 | 0 | 1 | 0
a7 | a6 | a5 | a4 | a3 | a2 | a1 | a0
JC addr | Jump if Carry is Set

(PC 0 – 7) ← addr; if C = 1
(PC) ← (PC) + 2; if C = 0

2 cycles

If Carry is set then a jump is executed to the Program Memory location addressed by the byte that follows the opcode. If it is not set then program execution continues with the next instruction.
1 | 1 | 1 | 1 | 0 | 1 | 1 | 0
a7 | a6 | a5 | a4 | a3 | a2 | a1 | a0

35

JF0 addr | Jump if Flag 0 is Set

(PC 0 – 7) ← addr; if F0 = 1
(PC) ← (PC) + 2; if F0 = 0

2 cycles

If Flag 0 is set then a jump is executed to the Program Memory location addressed by the byte that follows the opcode. If it is not set then program execution continues with the next instruction.
Note: This instruction is not available for the 8021/8022.
1 | 0 | 1 | 1 | 0 | 1 | 1 | 0
a7 | a6 | a5 | a4 | a3 | a2 | a1 | a0
JF1 addr | Jump if Flag 1 is Set

(PC 0 – 7) ← addr; if F1 = 1
(PC) ← (PC) + 2; if F1 = 0

2 cycles

If Flag 1 is set then a jump is executed to the Program Memory location addressed by the byte that follows the opcode. If it is not set then program execution continues with the next instruction.
Note: This instruction is not available for the 8021/8022.
0 | 1 | 1 | 1 | 0 | 1 | 1 | 0
a7 | a6 | a5 | a4 | a3 | a2 | a1 | a0
JMP addr | Direct Jump

(PC 8 – 10) ← addr 8 – 10
(PC 0 – 7) ← addr 0 – 7
(PC 11) ← DBF

2 cycles

Program execution continues at the Program Memory location addressed by addr. Bit 11 of the Program Counter is initialized with DBF (determined by last SEL MBx instruction).

a10 | a9 | a8 | 0 | 0 | 1 | 0 | 0
a7 | a6 | a5 | a4 | a3 | a2 | a1 | a0
JMPP @ A | Indirect Jump Within Page
(PC 0 – 7) ← ((A)) | 2 cycles
The contents of the Program Memory location addressed by the Accumulator is used as the new page offset of the Program Counter.
1 0 1 1 | 0 0 1 1
JNC addr | Jump if Carry is Not Set

(PC 0 – 7) ← addr; if C = 0
(PC) ← (PC) + 2; if C = 1

2 cycles

If Carry is not set then a jump is executed to the Program Memory location addressed by the byte that follows the opcode. If it is set then program execution continues with the next instruction.
1 | 1 | 1 | 0 | 0 | 1 | 1 | 0
a7 | a6 | a5 | a4 | a3 | a2 | a1 | a0
JNI addr | Jump if Interrupt Input is Low

(PC 0 – 7) ← addr; if I = 0
(PC) ← (PC) + 2; if I = 1

2 cycles

If the external interrupt input pin is low then a jump is executed to the Program Memory location addressed by the byte that follows the opcode. If it is high then program execution continues with the next instruction.
Note: This instruction is not available for the 8021/8022.
1 | 0 | 0 | 0 | 0 | 1 | 1 | 0
a7 | a6 | a5 | a4 | a3 | a2 | a1 | a0
JNT0 addr | Jump if Test 0 is Low

(PC 0 – 7) ← addr; if T0 = 0
(PC) ← (PC) + 2; if T0 = 1

2 cycles

If Test 0 is low then a jump is executed to the Program Memory location addressed by the byte that follows the opcode. If it is high then program execution continues with the next instruction.
Note: This instruction is not available for the 8021/8022.
0 | 0 | 1 | 0 | 0 | 1 | 1 | 0
a7 | a6 | a5 | a4 | a3 | a2 | a1 | a0
JNT1 addr | Jump if Test 1 is Low

(PC 0 – 7) ← addr; if T1 = 0
(PC) ← (PC) + 2; if T1 = 1

2 cycles

If Test 1 is low then a jump is executed to the Program Memory location addressed by the byte that follows the opcode. If it is high then program execution continues with the next instruction.
0 | 1 | 0 | 0 | 0 | 1 | 1 | 0
a7 | a6 | a5 | a4 | a3 | a2 | a1 | a0
JNZ addr | Jump if Accumulator is Not Zero

(PC 0 – 7) ← addr; if Accu ≠ 0
(PC) ← (PC) + 2; if Accu = 0

2 cycles

If the Accumulator contents is not all zero then a jump is executed to the Program Memory location addressed by the byte that follows the opcode. If it is all zero then program execution continues with the next instruction.
1 | 0 | 0 | 1 | 0 | 1 | 1 | 0
a7 | a6 | a5 | a4 | a3 | a2 | a1 | a0
JTF addr | Jump if Timer/Counter Flag is Set

(PC 0 – 7) ← addr; if T = 1
(PC) ← (PC) + 2; if T = 0

2 cycles

If the Timer/Counter flag is set then a jump is executed to the Program Memory location addressed by the byte that follows the opcode. If it is not set then program execution continues with the next instruction.
This instruction clears the Timer/Counter flag after it has been read.
0 0 0 1 | 0 1 1 0
a7 | a6 | a5 | a4 | a3 | a2 | a1 | a0
JT0 addr | Jump if Test 0 is High

(PC 0 – 7) ← addr; if T0 = 1
(PC) ← (PC) + 2; if T0 = 0

2 cycles

If Test 0 is high then a jump is executed to the Program Memory location addressed by the byte that follows the opcode. If it is low then program execution continues with the next instruction.
Note: This instruction is not available for the 8021/8022.
0 | 0 | 1 | 1 | 0 | 1 | 1 | 0
a7 | a6 | a5 | a4 | a3 | a2 | a1 | a0
JT1 addr | Jump if Test 1 is High

(PC 0 – 7) ← addr; if T1 = 1
(PC) ← (PC) + 2; if T1 = 0

2 cycles

If Test 1 is high then a jump is executed to the Program Memory location addressed by the byte that follows the opcode. If it is low then program execution continues with the next instruction.
0 | 1 | 0 | 1 | 0 | 1 | 1 | 0
a7 | a6 | a5 | a4 | a3 | a2 | a1 | a0

36

JZ addr | Jump if Accumulator is Zero

(PC 0 – 7) ← addr; if Accu = 0
(PC) ← (PC) + 2; if Accu ≠ 0

2 cycles

If the Accumulator contents is all zero then a jump is executed to the Program Memory location addressed by the byte that follows the opcode. If it is not all zero then program execution continues with the next instruction.
1 | 1 | 0 | 0 | 0 | 1 | 1 | 0
a7 | a6 | a5 | a4 | a3 | a2 | a1 | a0
MOV A, data | Move Immediate Data to Accumulator
(A) ← data | 2 cycles
The Accumulator is loaded with the contents of the Program Memory location that follows the opcode .
0 | 0 | 1 | 0 | 0 | 0 | 1 | 1
d7 | d6 | d5 | d4 | d3 | d2 | d1 | d0
MOV A, PSW | Move PSW Contents to Accumulator
(A) ← (PSW)
The contents of the PSW is copied into the Accumulator. Note: This instruction is not available for the 8021/8022.
1 | 1 | 0 | 0 | 0 | 1 | 1 | 1
MOV A, Rr | Move Register Contents to Accumulator
(A) ← (Rr) | r = 0 – 7
The contents of register Rr is copied into the Accumulator.
1 | 1 | 1 | 1 | 1 | r | r | r
MOV A, @ Rr | Move Data Memory Contents to Accumulator
(A) ← ((Rr)) | r = 0 – 1
The contents of the Data Memory location addressed by bits 0 – 5 (0 – 6 for the 8039/8049) is copied into the Accumulator.
1 | 1 | 1 | 1 | 0 | 0 | 0 | r
MOV A, T | Move Timer/Counter Contents to Accumulator
(A) ← (T)
The contents of the Timer/Counter register is copied into the Accumulator.
0 | 1 | 0 | 0 | 0 | 0 | 1 | 0
MOV PSW, A | Move Accumulator Contents to PSW

(PSW) ← (A)
The contents of the Accumulator is copied into the PSW (all bits). Note: This instruction is not available for the 8021/8022.
1 | 1 | 0 | 1 | 0 | 1 | 1 | 1
MOV Rr, A | Move Accumulator Contents to Register
(Rr) ← (A) | r = 0 – 7
The contents of the Accumulator is copied into register Rr.
1 | 0 | 1 | 0 | 1 | r | r | r
MOV Rr, data | Move Immediate Data into Register
(Rr) ← data | r = 0 – 7 | 2 cycles
The contents of the Program Memory location that follows the opcode is copied into register Rr.
1 | 0 | 1 | 1 | 1 | r | r | r
d7 | d6 | d5 | d4 | d3 | d2 | d1 | d0
MOV @ Rr, A | Move Accumulator Contents to Data Memory
((Rr)) ← (A) | r = 0 – 1
The contents of the Accumulator is copied into the Data Memory location addressed by bits 0 – 5 (0 – 6 for the 8039/8049).
1 | 0 | 1 | 0 | 0 | 0 | 0 | r
MOV @ Rr, data | Move Immediate Data to Data Memory
((Rr)) ← data | r = 0 – 1 | 2 cycles
The byte that follows the opcode is copied into the Data Memory location addressed by bits 0 – 5 (0 – 6 for 8039/8049) of register Rr.
1 | 0 | 1 | 1 | 0 | 0 | 0 | r
d7 | d6 | d5 | d4 | d3 | d2 | d1 | d0
MOV T, A | Move Accumulator Contents to Timer/Counter
(T) ← (A)
The contents of the Accumulator is copied into the Timer/Counter register.
0 | 1 | 1 | 0 | 0 | 0 | 1 | 0
MOVD A, Pp | Move Port 4 – 7 Data to Accumulator

(A 0 – 3) ← (Pp)
(A 4 – 7) ← 0
p = 4 – 7 | 2 cycles

Port p is read and its bits 0 – 3 are copied into the Accumulator. Bits 4 – 7 of the Accumulator are cleared to 0.
See the ANLD Pp, A instruction for coding of the p field.
0 | 0 | 0 | 0 | 1 | 1 | p | p
MOVD Pp, A | Move Accumulator Data to Port 4 – 7
(Pp) ← (A 0 – 3) | p = 4 – 7 | 2 cycles
Bits 0 – 3 of the Accumulator are copied to port p.
See the ANLD Pp, A instruction for coding of the p field.
0 | 0 | 1 | 1 | 1 | 1 | p | p
MOVP A, @ A | Move Current Page Data to Accumulator

(PC 0 – 7) ← (A)
(A) ← ((PC))

2 cycles

The contents of the Program Memory location addressed by the Accumulator is copied into the Accumulator. Only bits 0 – 7 of the Program Counter are affected. Therefore, the instruction is restricted to the current page. The Program Counter is restored after the operation. Note: If the instruction is located at address 255 of the current page then the next page is addressed with the Accumulator as offset.

1 | 0 | 1 | 0 | 0 | 0 | 1 | 1

37

MOVP3 A, @ A | Move Page 3 Data to Accumulator

(PC 0 – 7) ← (A)
(PC 8 – 11) ← 0011
(A) ← ((PC))

2 cycles

The contents of the Program Memory location addressed by the Accumulator in page 3 is copied into the Accumulator. The Program Counter is restored after the operation.

1 1 1 0 | 0 0 1 1
MOVX A, @ Rr | Move External Data Memory Contents to
Accumulator
(A) ← ((Rr)) | r = 0 – 1 | 2 cycles
The contents of the external Data Memory location addressed by register Rr is copied into the Accumulator.
Note: This instruction is not available for the 8021/8022.
1 | 0 | 0 | 0 | 0 | 0 | 0 | r
MOVX @ Rr, A | Move Accumulator Contents to External Data
Memory
((Rr)) ← (A) | r = 0 – 1 | 2 cycles
The contents of the Accumulator is copied to the external Data Memory location addressed by register Rr.
Note: This instruction is not available for the 8021/8022.
1 | 0 | 0 | 1 | 0 | 0 | 0 | r
NOP | No Operation

No operation is executed. Program execution continues with the next instruction.

0 | 0 | 0 | 0 | 0 | 0 | 0 | 0
ORL A, Rr | Logical OR Accumulator With Register Mask
(A) ← (A) (Rr) ∨ | r = 0 – 7
The contents of the Accumulator is logically (bitwise) ored with the contents of register Rr.
0 | 1 | 0 | 0 | 1 | r | r | r
ORL A, @ Rr | Logical OR Accumulator With Memory Mask
(A) ← (A) ((Rr)) ∨ | r = 0 – 1
The contents of the Accumulator is logically (bitwise) ored with the contents of the Data Memory location addressed by bits 0 – 5 (0 – 6 for the 8039/8049).
0 | 1 | 0 | 0 | 0 | 0 | 0 | r
ORL A, data | Logical OR Accumulator With Immediate Mask
(A) ← (A) data ∨ | 2 cycles
The contents of the Accumulator is logically (bitwise) ored with the contents of the Program Memory location following the opcode.
0 | 1 | 0 | 0 | 0 | 0 | 1 | 1
d7 | d6 | d5 | d4 | d3 | d2 | d1 | d0
ORL BUS, data | Logical OR BUS with Immediate Mask
(BUS) ← (BUS) data ∨ | 2 cycles
BUS is read and its contents is logically (bitwise) ored with the contents of the byte that follows the opcode. This instruction requires the instruction OUTL BUS, A to be executed in advance.
Note: This instruction is not available for the 8021/8022. It must not be used with the 8035/8039 as BUS is used for external Program Memory access.
1 0 0 0 | 1 0 0 0
d7 | d6 | d5 | d4 | d3 | d2 | d1 | d0
ORL Pp, data | Logical OR Port 1 – 2 With Immediate Mask
(Pp) ← (Pp) data ∨ | p = 1 – 2 | 2 cycles
Port p is read and its contents is logically (bitwise) ored with the contents of the byte that follows the opcode.
Note: This instruction is not available for the 8021/8022.
1 | 0 | 0 | 0 | 1 | 0 | p | p
d7 | d6 | d5 | d4 | d3 | d2 | d1 | d0
ORLD Pp, A | Logical OR Port 4 – 7 With Accumulator Mask
(Pp) ← (Pp) A(0 – 3) ∨ | p = 4 – 7 | 2 cycles
Port p is read and its bits 0 – 3 are logically (bitwise) ored with bits 0 - 3 of the Accumulator.
See the ANLD Pp, A instruction for coding of the p field.
Note: This instruction is not available for the 8021/8022.
1 | 0 | 0 | 0 | 1 | 1 | p | p
OUTL P0, A | Output Accumulator Data to Port 0

Note: This instruction is only available for the 8021/8022.

1 | 0 | 0 | 1 | 0 | 0 | 0 | 0
OUTL BUS, A | Output Accumulator Data to BUS
(BUS) ← (A) | 2 cycles
The contents of the Accumulator is put on the BUS with a low-strobe on WR'. The BUS lines maintain their contents until the next OUTL BUS, A instruction. All other instructions related to BUS (except INS A, BUS) destroy the BUS state. This also includes the MOVX instructions.
Note: This instruction is not available for the 8021/8022.
0 | 0 | 0 | 0 | 0 | 0 | 1 | 0
OUTL Pp, A | Output Accumulator Data to Port 1 – 2
(Pp) ← (A) | p = 1 – 2 | 2 cycles
The contents of the Accumulator is put on port p. The port lines maintain their contents until they are modified by another instruction related to port Pp.
0 | 0 | 1 | 1 | 1 | 0 | p | p
RAD | Move Conversion Result Register to Accumulator

2 cycles
The contents of the A/D result register is copied into the Accumulator. Note: This instruction is only available for the 8022.
1 | 0 | 0 | 0 | 0 | 0 | 0 | 0

38

RET | Return Without PSW Restore

(SP) ← (SP) – 1
(PC) ← ((SP))

2 cycles

The Program Stack Counter is decremented by 1. Using this new address, the Program Counter is restored from the Program Stack. Bits 4 – 7 of the PSW are not restored.

1 | 0 | 0 | 0 | 0 | 0 | 1 | 1
RETI | Return from Interrupt

(SP) ← (SP) – 1
(PC) ← ((SP)) + 1

2 cycles

The Program Stack Counter is decremented by 1. Using this new address, the Program Counter is restored from the Program Stack.
The interrupt logic enables a new interrupt request.
Note: This instruction is only available for the 8022.
1 | 0 | 0 | 1 | 0 | 0 | 1 | 1
RETR | Return With PSW Restore

(SP) ← (SP) – 1
(PC) ← ((SP))
(PSW 4 – 7) ← ((SP))

2 cycles

The Program Stack Counter is decremented by 1. Using this new address, the Program Counter is restored from the Program Stack. In addition, bits 4 – 7 of the PSW are restored from the Program Stack. This instruction should only be used to return from an interrupt service subroutine. Moreover, it should not be used for call/returns within the interrupt service routine as it clears the interrupt flag and thus enables a new interrupt request to be processed by the system (interrupt nesting). Note: This instruction is not available for the 8021/8022.

1 | 0 | 0 | 1 | 0 | 0 | 1 | 1
RL A | Rotate Left Without Carry

(A n+1) ← (A n); n = 0 – 6
(A 0) ← (A 7)
The contents of the Accumulator is rotated left by one bit position.
1 | 1 | 1 | 0 | 0 | 1 | 1 | 1
RLC A | Rotate Left With Carry

(A n+1) ← (A n); n = 0 – 6
(A 0) ← (C)
(C) ← (A 7)
The contents of the Accumulator is rotated left through Carry by one bit position.
1 | 1 | 1 | 1 | 0 | 1 | 1 | 1
RR A | Rotate Right Without Carry

(A n) ← (A n+1); n = 0 – 6
(A 7) ← (A 0)
The contents of the Accumulator is rotated right by one bit position.
0 1 1 1 | 0 1 1 1
RRC A | Rotate Right With Carry
| (A n) ← (A n+1); n = 0 – 6
(A 7) ← (C)
(C) ← (A 0)
| The contents of the Accumulator is rotated right through Carry by one
bit position.
0 1 1 0 | 0 1 1 1
SEL AN0 | Select Analog Input 0

Input 0 of the A/D converter is selected and a new conversion is started. A running conversion is aborted and restarted.
Note: This instruction is only available for the 8022.
1 | 0 | 0 | 1 | 0 | 1 | 0 | 1
SEL AN1 | Select Analog Input 1

Input 1 of the A/D converter is selected and a new conversion is started. A running conversion is aborted and restarted.
Note: This instruction is only available for the 8022.
1 | 0 | 0 | 0 | 0 | 1 | 0 | 1
SEL MB0 | Select Memory Bank 0

(DBF) ← 0
MBF is set to 0, selecting bank 0 of the Program Memory. The following JMP and CALL instructions will target the locations 0 – 2047 of the Program Memory.
Note: This instruction is not available for the 8021/8022.
1 | 1 | 1 | 0 | 0 | 1 | 0 | 1
SEL MB1 | Select Memory Bank 1

(DBF) ← 1
MBF is set to 1, selecting bank 1 of the Program Memory. The following JMP and CALL instructions will target the locations 2048 – 4095 of the Program Memory.
Note: This instruction is not available for the 8021/8022.
1 | 1 | 1 | 1 | 0 | 1 | 0 | 1
SEL RB0 | Select Register Bank 0

(BS) ← 0
Bit 4 of PSW is set to 0. Registers 0 – 7 are mapped to Data Memory locations 0 – 7. This is the recommended setting for normal program execution.
Note: This instruction is not available for the 8021/8022.
1 | 1 | 0 | 0 | 0 | 1 | 0 | 1
SEL RB1 | Select Register Bank 1

(BS) ← 1
Bit 4 of PSW is set to 1. Register s0 – 7 are mapped to Data Memory locations 24 – 31.
This is the recommended setting for interrupt service subroutines as Data Memory locations 0 – 7 are not modified. The RETR instruction at the end of the interrupt subroutine will restore BS (bit 4 of PSW).
Note: This instruction is not available for the 8021/8022.
1 | 1 | 0 | 1 | 0 | 1 | 0 | 1
STOP TCNT | Stop Timer/Counter

The Timer/Counter is stopped.

0 1 1 0 | 0 1 0 1
STRT CNT | Start Event Counter

T1 is declared as input for the Event Counter. Every high-to-low transition at T1 increments the counter register by 1.

0 1 0 0 | 0 1 0 1

39

STRT T | Start Timer

The internal clock is declared as input for the Timer Counter. After 32 machine cycles, the counter register is incremented by 1. This instruction resets the prescaler to 0 by does not change the counter register.

0 | 1 | 0 | 1 | 0 | 1 | 0 | 1
SWAP A | Swap Nibbles Within Accumulator

(A 4 – 7) ⇄ (A 0 – 3)
Bits 0 – 3 and 4 – 7 of the Accumulator are swapped.
0 | 1 | 0 | 0 | 0 | 1 | 1 | 1
XCH A, Rr | Exchange Accumulator and Register Contents
(A) | (Rr) ⇄ | r = 0 – 7
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

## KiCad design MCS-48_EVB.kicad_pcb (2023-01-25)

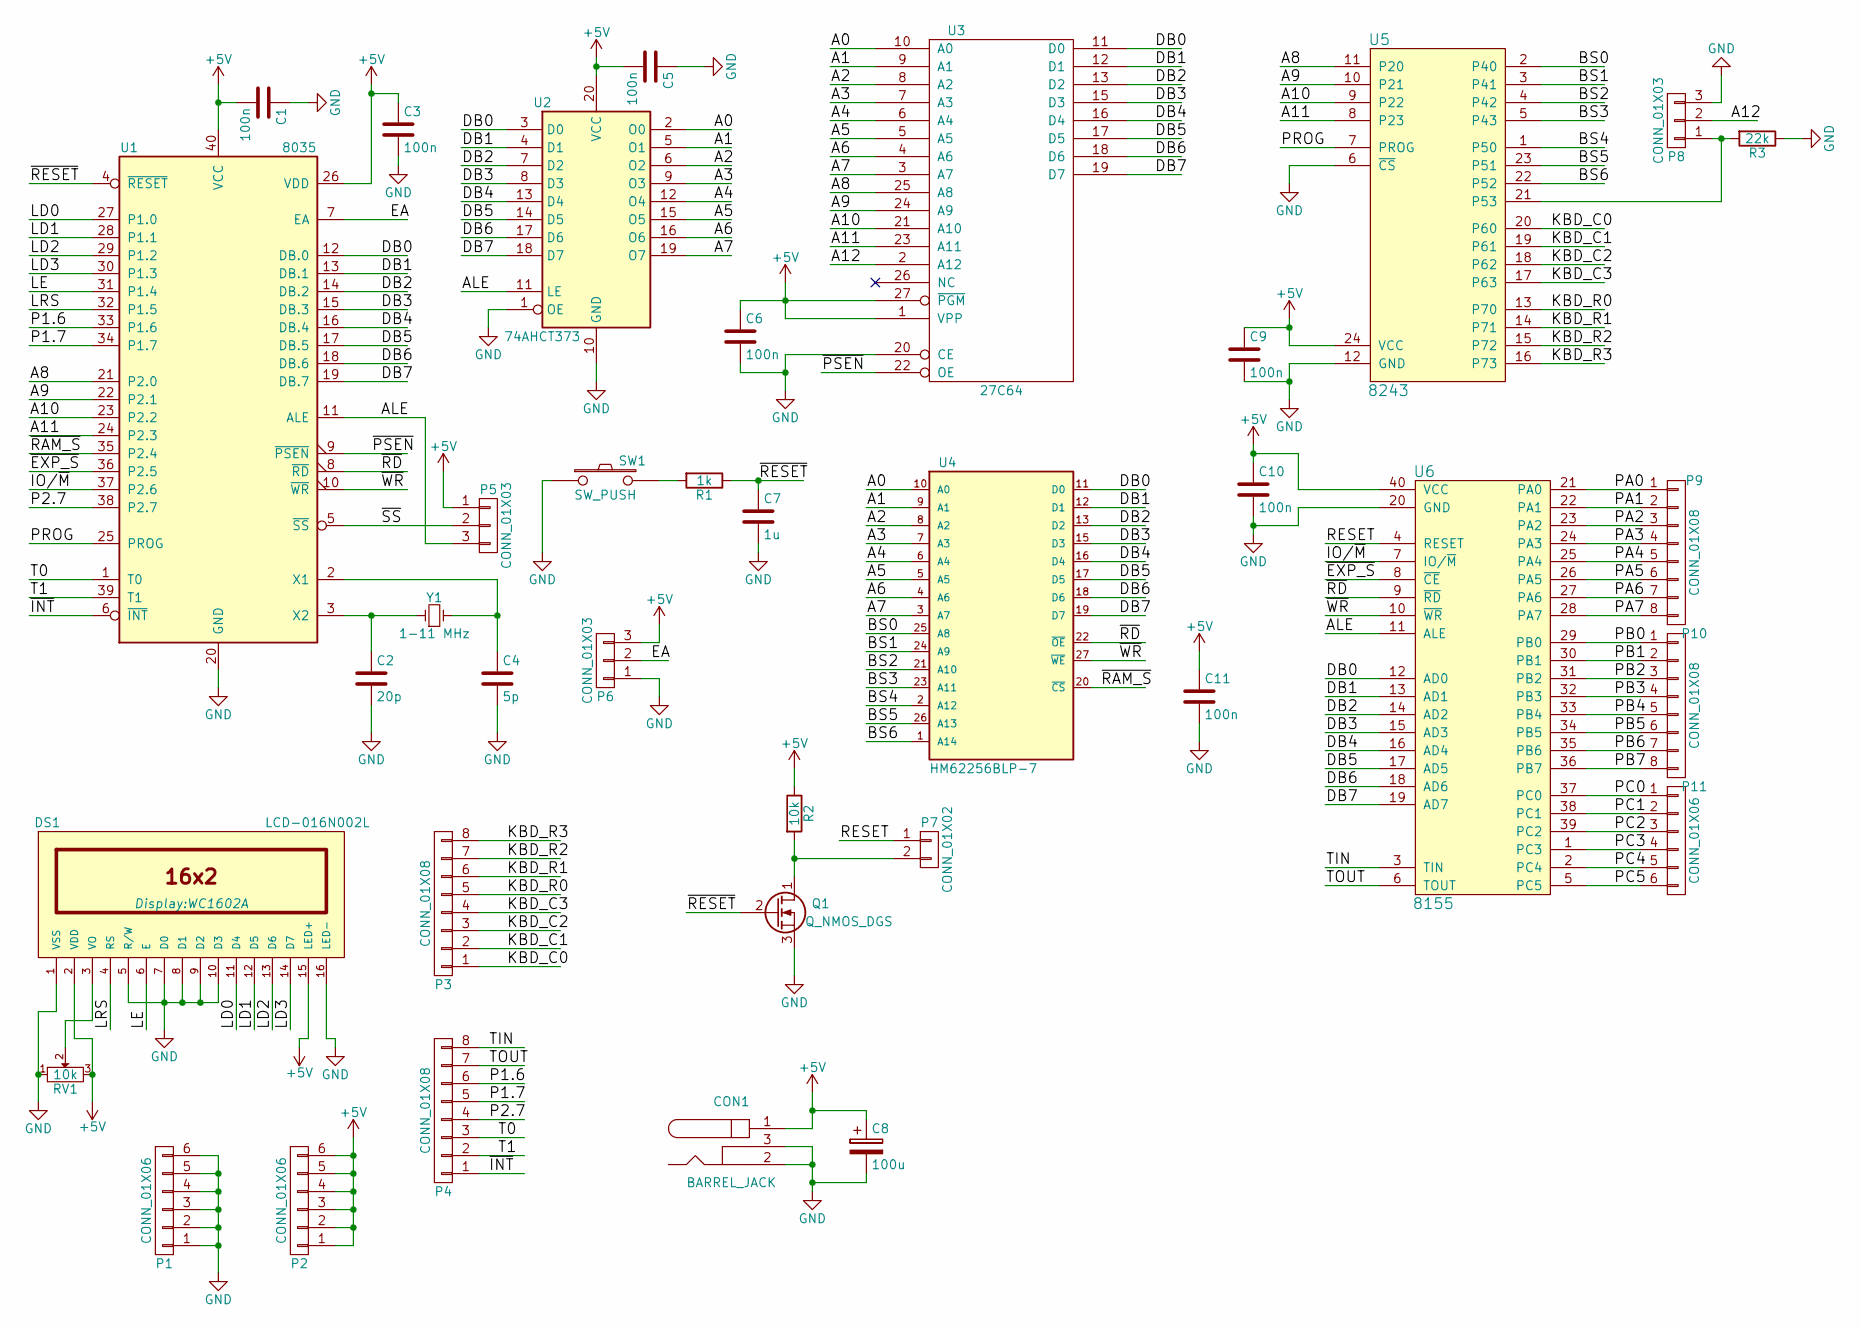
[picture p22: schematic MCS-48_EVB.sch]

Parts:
C1, C3, C5, C6, C9, C10, C11: 100n; C_0805_HandSoldering
C2: 20p; C_0805_HandSoldering
C4: 5p; C_0805_HandSoldering
C7: 1u; C_0805_HandSoldering
C8: 100u; CP_Radial_D6.3mm_P2.50mm
CON1: BARREL_JACK
DS1: LCD-016N002L; WC1602A
P1, P2, P11: CONN_01X06; Pin_Header_Straight_1x06_Pitch2.54mm
P3, P4, P9, P10: CONN_01X08; Pin_Header_Straight_1x08_Pitch2.54mm
P5, P6, P8: CONN_01X03; Pin_Header_Straight_1x03_Pitch2.54mm
P7: CONN_01X02; Pin_Header_Straight_1x02_Pitch2.54mm
Q1: Q_NMOS_DGS; TO-92_Inline_Narrow_Oval
R1: 1k; R_0805_HandSoldering
R2: 10k; R_0805_HandSoldering
R3: 22k; R_0805_HandSoldering
RV1: 10k; Potentiometer_Trimmer_ACP_CA9v_Horizontal_Px10.0mm_Py5.0mm
SW1: SW_PUSH; SW_PUSH_6mm
U1: 8035; DIP-40_W15.24mm_LongPads
U2: 74AHCT373; DIP-20_W7.62mm_LongPads
U3: 27C64; DIP-28_W15.24mm_LongPads
U4: HM62256BLP-7; DIP-28_W15.24mm_LongPads
U5: 8243; DIP-24_W15.24mm_LongPads
U6: 8155; DIP-40_W15.24mm_LongPads
Y1: 1-11 MHz; Crystal_HC18-U_Vertical

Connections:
+5V: C1.2, C3.1, C5.2, C6.1, C8.1, C9.1, C10.1, C11.1, CON1.1, DS1.2 (VDD), DS1.15 (LED+), P2.1, P2.2, P2.3, P2.4, P2.5, P2.6, P5.1, P6.3, R2.1, RV1.3, U1.26 (VDD), U1.40 (VCC), U2.20 (VCC), U3.1 (VPP), U3.27 (~PGM), U3.28 (VCC), U4.28 (VCC), U5.24 (VCC), U6.40 (VCC)
/A0: U2.2 (O0), U3.10 (A0), U4.10 (A0)
/A1: U2.5 (O1), U3.9 (A1), U4.9 (A1)
/A2: U2.6 (O2), U3.8 (A2), U4.8 (A2)
/A3: U2.9 (O3), U3.7 (A3), U4.7 (A3)
/A4: U2.12 (O4), U3.6 (A4), U4.6 (A4)
/A5: U2.15 (O5), U3.5 (A5), U4.5 (A5)
/A6: U2.16 (O6), U3.4 (A6), U4.4 (A6)
/A7: U2.19 (O7), U3.3 (A7), U4.3 (A7)
/A8: U1.21 (P2.0), U3.25 (A8), U5.11 (P20)
/A9: U1.22 (P2.1), U3.24 (A9), U5.10 (P21)
/A10: U1.23 (P2.2), U3.21 (A10), U5.9 (P22)
/A11: U1.24 (P2.3), U3.23 (A11), U5.8 (P23)
/A12: P8.2, U3.2 (A12)
/ALE: P5.3, U1.11 (ALE), U2.11 (LE), U6.11 (ALE)
/BS0: U4.25 (A8), U5.2 (P40)
/BS1: U4.24 (A9), U5.3 (P41)
/BS2: U4.21 (A10), U5.4 (P42)
/BS3: U4.23 (A11), U5.5 (P43)
/BS4: U4.2 (A12), U5.1 (P50)
/BS5: U4.26 (A13), U5.23 (P51)
/BS6: U4.1 (A14), U5.22 (P52)
/DB0: U1.12 (DB.0), U2.3 (D0), U3.11 (D0), U4.11 (D0), U6.12 (AD0)
/DB1: U1.13 (DB.1), U2.4 (D1), U3.12 (D1), U4.12 (D1), U6.13 (AD1)
/DB2: U1.14 (DB.2), U2.7 (D2), U3.13 (D2), U4.13 (D2), U6.14 (AD2)
/DB3: U1.15 (DB.3), U2.8 (D3), U3.15 (D3), U4.15 (D3), U6.15 (AD3)
/DB4: U1.16 (DB.4), U2.13 (D4), U3.16 (D4), U4.16 (D4), U6.16 (AD4)
/DB5: U1.17 (DB.5), U2.14 (D5), U3.17 (D5), U4.17 (D5), U6.17 (AD5)
/DB6: U1.18 (DB.6), U2.17 (D6), U3.18 (D6), U4.18 (D6), U6.18 (AD6)
/DB7: U1.19 (DB.7), U2.18 (D7), U3.19 (D7), U4.19 (D7), U6.19 (AD7)
/EA: P6.2, U1.7 (EA)
/IO/~M: U1.37 (P2.6), U6.7 (IO/~M)
/KBD_C0: P3.1, U5.20 (P60)
/KBD_C1: P3.2, U5.19 (P61)
/KBD_C2: P3.3, U5.18 (P62)
/KBD_C3: P3.4, U5.17 (P63)
/KBD_R0: P3.5, U5.13 (P70)
/KBD_R1: P3.6, U5.14 (P71)
/KBD_R2: P3.7, U5.15 (P72)
/KBD_R3: P3.8, U5.16 (P73)
/LD0: DS1.11 (D4), U1.27 (P1.0)
/LD1: DS1.12 (D5), U1.28 (P1.1)
/LD2: DS1.13 (D6), U1.29 (P1.2)
/LD3: DS1.14 (D7), U1.30 (P1.3)
/LE: DS1.6 (E), U1.31 (P1.4)
/LRS: DS1.4 (RS), U1.32 (P1.5)
/P1.6: P4.6, U1.33 (P1.6)
/P1.7: P4.5, U1.34 (P1.7)
/P2.7: P4.4, U1.38 (P2.7)
/PA0: P9.1, U6.21 (PA0)
/PA1: P9.2, U6.22 (PA1)
/PA2: P9.3, U6.23 (PA2)
/PA3: P9.4, U6.24 (PA3)
/PA4: P9.5, U6.25 (PA4)
/PA5: P9.6, U6.26 (PA5)
/PA6: P9.7, U6.27 (PA6)
/PA7: P9.8, U6.28 (PA7)
/PB0: P10.1, U6.29 (PB0)
/PB1: P10.2, U6.30 (PB1)
/PB2: P10.3, U6.31 (PB2)
/PB3: P10.4, U6.32 (PB3)
/PB4: P10.5, U6.33 (PB4)
/PB5: P10.6, U6.34 (PB5)
/PB6: P10.7, U6.35 (PB6)
/PB7: P10.8, U6.36 (PB7)
/PC0: P11.1, U6.37 (PC0)
/PC1: P11.2, U6.38 (PC1)
/PC2: P11.3, U6.39 (PC2)
/PC3: P11.4, U6.1 (PC3)
/PC4: P11.5, U6.2 (PC4)
/PC5: P11.6, U6.5 (PC5)
/PROG: U1.25 (PROG), U5.7 (PROG)
/RESET: P7.1, U6.4 (RESET)
/T0: P4.3, U1.1 (T0)
/T1: P4.2, U1.39 (T1)
/TIN: P4.8, U6.3 (TIN)
/TOUT: P4.7, U6.6 (TOUT)
/~EXP_S: U1.36 (P2.5), U6.8 (~CE)
/~INT: P4.1, U1.6 (~INT~)
/~PSEN: U1.9 (~PSEN~), U3.22 (OE)
/~RAM_S: U1.35 (P2.4), U4.20 (~CS)
/~RD: U1.8 (~RD~), U4.22 (~OE), U6.9 (~RD)
/~RESET: C7.1, Q1.2 (G), R1.1, U1.4 (~RESET~)
/~SS: P5.2, U1.5 (~SS~)
/~WR: U1.10 (~WR~), U4.27 (~WE), U6.10 (~WR)
GND: C1.1, C2.2, C3.2, C4.2, C5.1, C6.2, C7.2, C8.2, C9.2, C10.2, C11.2, CON1.2, CON1.3, DS1.1 (VSS), DS1.5 (R/W), DS1.7 (D0), DS1.8 (D1), DS1.9 (D2), DS1.10 (D3), DS1.16 (LED-), P1.1, P1.2, P1.3, P1.4, P1.5, P1.6, P6.1, P8.3, Q1.3 (S), R3.1, RV1.1, SW1.1, U1.20 (GND), U2.1 (OE), U2.10 (GND), U3.14 (GND), U3.20 (CE), U4.14 (GND), U5.6 (~CS), U5.12 (GND), U6.20 (GND)
unnamed: C2.1, U1.3 (X2), Y1.1
unnamed: C4.1, U1.2 (X1), Y1.2
unnamed: DS1.3 (VO), RV1.2
unnamed: P7.2, Q1.1 (D), R2.2
unnamed: P8.1, R3.2, U5.21 (P53)
unnamed: R1.2, SW1.2

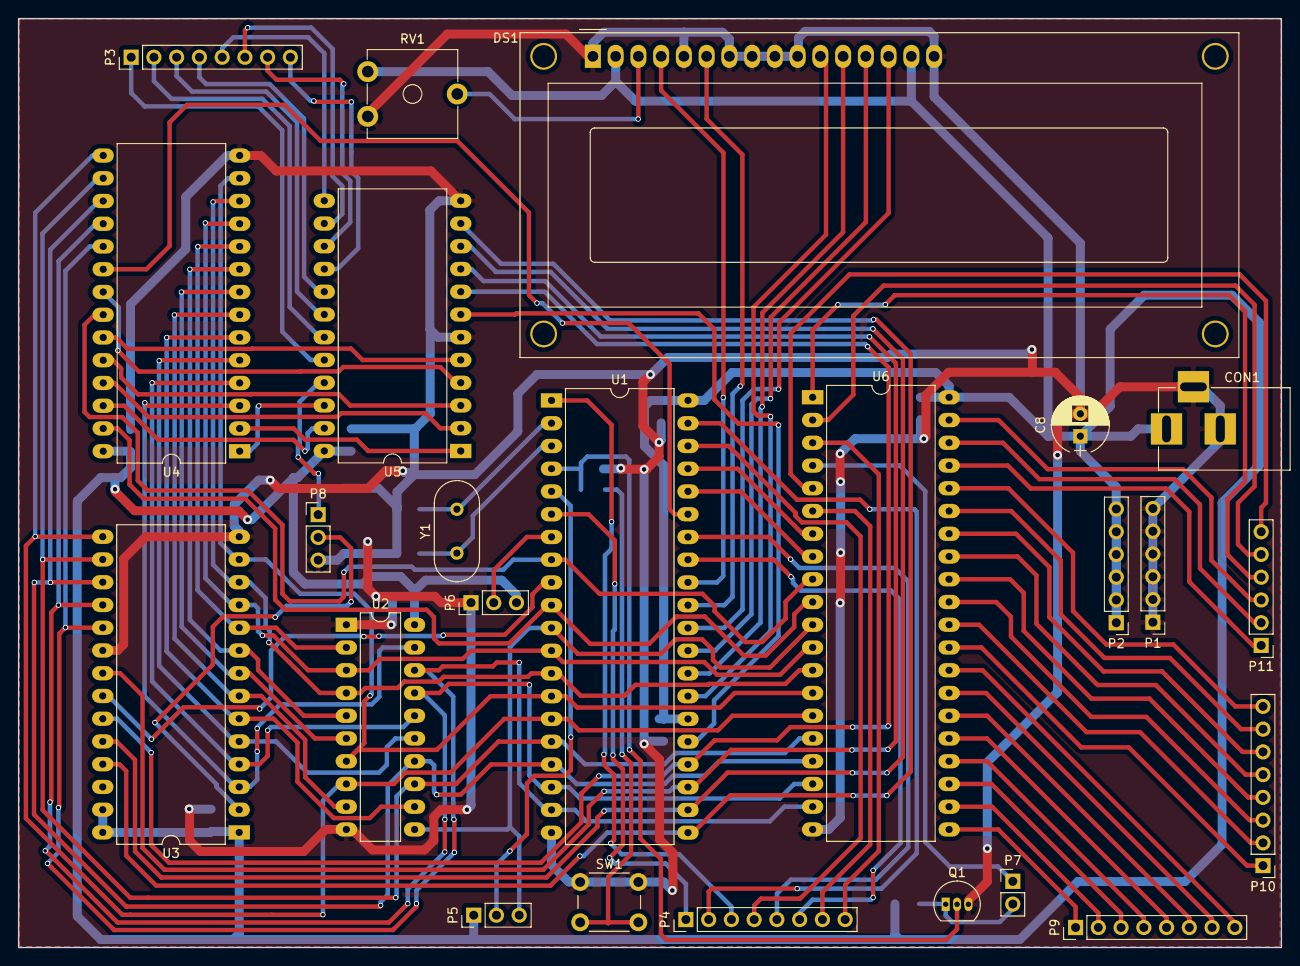
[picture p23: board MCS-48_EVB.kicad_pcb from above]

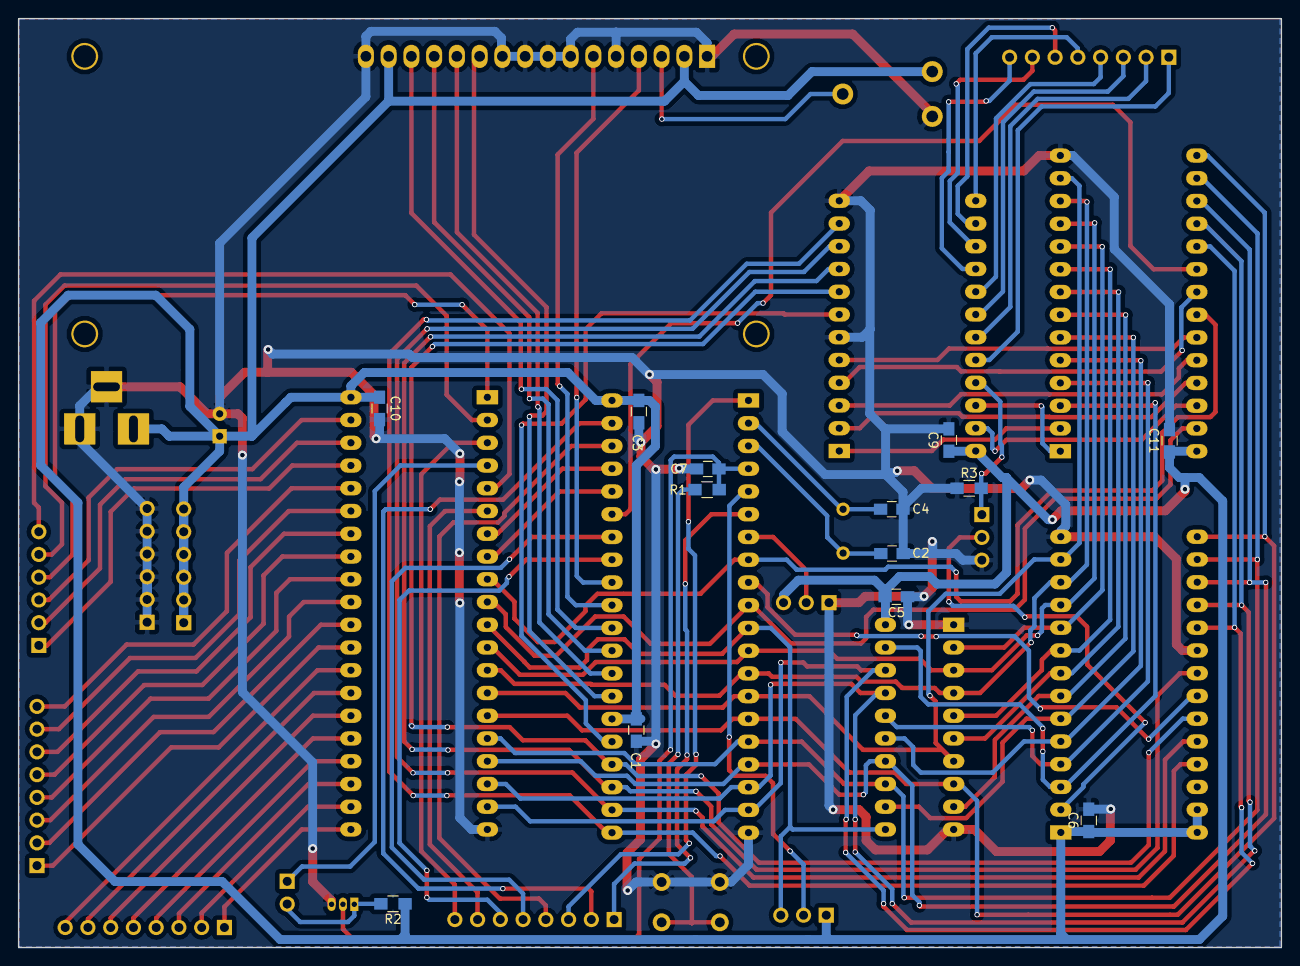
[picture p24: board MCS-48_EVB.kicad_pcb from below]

Board: 2 copper layers, 141.0 x 103.7 mm, 37 parts (13 on the bottom side), 92 nets.

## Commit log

2023-01-03 Started working on schematic.
    [MCS-48_EVB.kicad_pcb, MCS-48_EVB.sch]
2023-01-06 Added memories & expander
    [MCS-48_EVB.sch]
2023-01-06 Added RESET and EA circuits. Added MCS-48 docs.
    [MCS-48_EVB.sch]
2023-01-06 Added IC footprints
    [MCS-48_EVB.sch]
2023-01-07 Added 8155 expander
    [MCS-48_EVB.sch]
2023-01-07 Added LCD & keyb conn
    [MCS-48_EVB.sch]
2023-01-07 Added connectors. Power connector and step mode circuit left.
    [MCS-48_EVB.sch]
2023-01-08 Started working on PCB.
    [MCS-48_EVB.kicad_pcb, MCS-48_EVB.sch]
2023-01-09 Working on component placement
    [MCS-48_EVB.kicad_pcb]
2023-01-09 Finished component placement.
    [MCS-48_EVB.kicad_pcb, MCS-48_EVB.sch]
2023-01-09 Added board outline.
    [MCS-48_EVB.kicad_pcb]
2023-01-15 Working on spaghetti-tracing
    [MCS-48_EVB.kicad_pcb]
2023-01-15 Working on spaghetti-tracing. Only GND left.
    [MCS-48_EVB.dsn, MCS-48_EVB.kicad_pcb]
2023-01-15 All nets connected
    [MCS-48_EVB.kicad_pcb]
2023-01-15 Added GND planes
    [MCS-48_EVB.kicad_pcb]
2023-01-15 Generated gerber files
    [MCS-48_EVB-B.Cu.gbl, MCS-48_EVB-B.Mask.gbs, MCS-48_EVB-B.SilkS.gbo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]
2023-01-25 Corrected gerber files
    [MCS-48_EVB-B.Cu.gbl, MCS-48_EVB-B.Mask.gbs, MCS-48_EVB-B.SilkS.gbo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]
